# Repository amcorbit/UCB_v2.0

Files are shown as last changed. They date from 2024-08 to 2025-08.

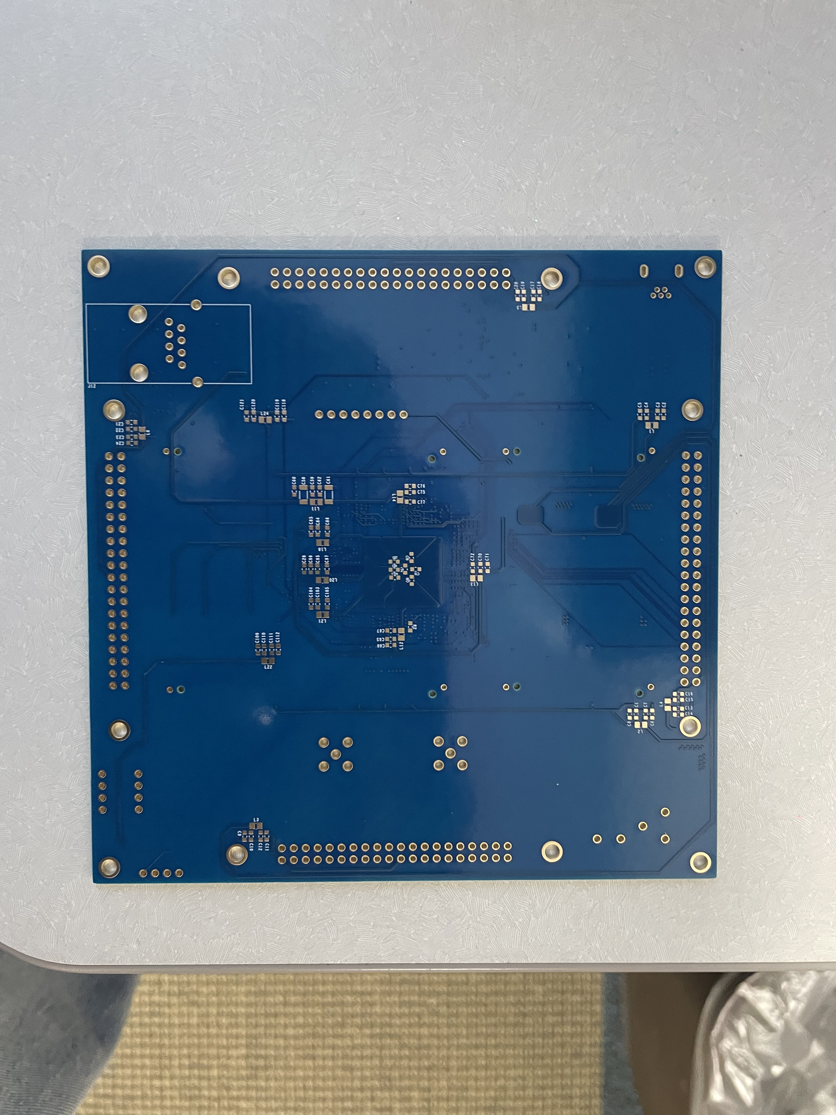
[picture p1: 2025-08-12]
Photos/IMG_9687 (1).jpeg

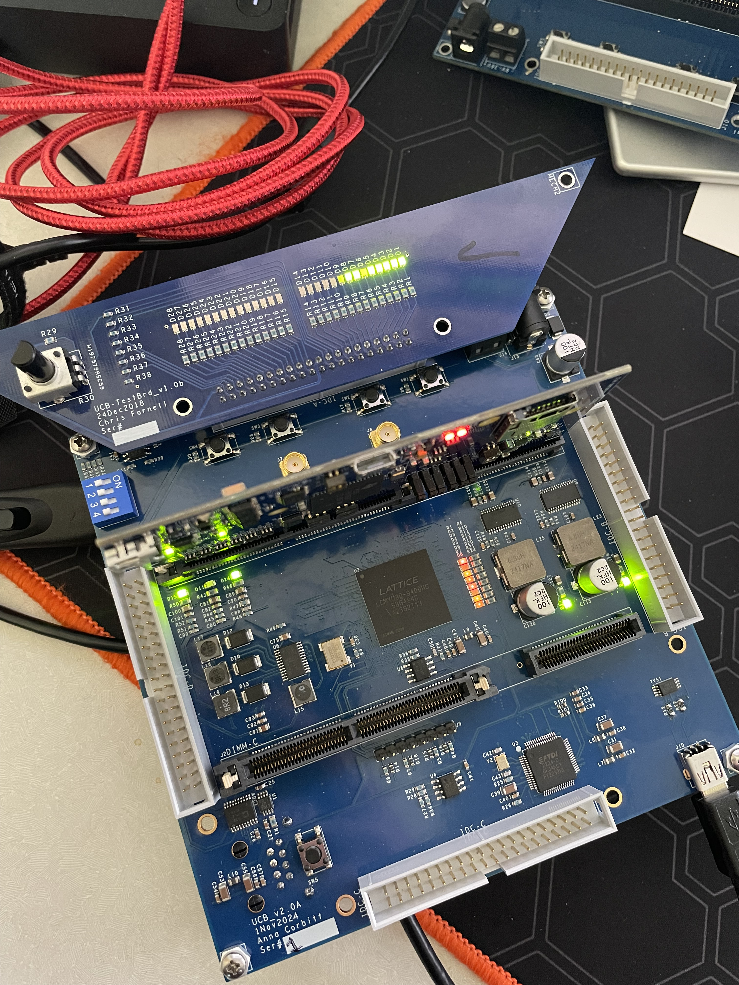
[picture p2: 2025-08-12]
Photos/IMG_9736 (1).jpeg

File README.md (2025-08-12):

This board was developed at the National Center for Reliable Electric Power Transmission (NCREPT) in collaboration with the University of Arkansas Power Group. It is an updated version of UCB v1.4a, which was developed by Dr. Chris Farnell. 

UCB v2.0 is an updated version of the existing UCB v1.4 architecture with additional features but a similar layout. 
The new version of the UCB includes an onboard SPI flash for storing and transferring information such as updated firmware. 
UCB v2.0 utilizes the Lattice MachXO3D FPGA instead of the MachXO2 for enhanced cybersecurity. 
The 100-Pin DIM slots on the original UCB v1.4 have been replaced with Texas Instruments’180-pin HSEC8 interface, allowing for the TMS320F28335 single core DSPs to be replaced with the TMS320F28379D dual core DSPs.
When compared to the F28335 DSP, the F28379D DSP has two 32-bit CPUs, a faster 200 MHz clock speed, additional programmable GPIO pins, an increased number of Pulse Width Modulator (PWM) channels, a larger flash, three SPI modules, and a 16-bit ADC.

Engineer: Anna Corbitt

Acknowledgments:

NCREPT Website: https://ncrept.uark.edu/

NCREPT Citation: A. Corbitt, W. G. Schwartz, C. Farnell, J. C. Balda and H. A. Mantooth, "The National Center for Reliable Electric Power Transmission Test Facility," in IEEE Open Journal of Power Electronics, vol. 5, pp. 754-764, 2024, doi: 10.1109/OJPEL.2024.3405311. 
Abstract: Globally, new technological solutions are being studied and developed by researchers in the field of power and energy systems. Before these solutions can be integrated into society as marketable products, thorough testing and validation of the design must be conducted. 
The National Center for Reliable Electric Power Transmission (NCREPT) is a unique high-power test facility located at the University of Arkansas, Fayetteville, AR, USA. NCREPT is a 12,000-square-foot laboratory space capable of testing power levels up to 6 MVA and offers testing at both the 480 V and 13.8 kV levels. 
NCREPT's capabilities expand outside of the scope of simply high-power testing. NCREPT has also supported experimental testing for transportation electrification, hardware-in-the-loop, and cybersecurity applications. 
NCREPT has personnel with experience testing new technologies and has demonstrated its innovative approaches by being a part of four R&D 100 award-winning projects. This paper gives an extensive overview of NCREPT, highlighting its significance as a state-of-the-art testing laboratory.

UA Power Group Website: https://uapower.group/

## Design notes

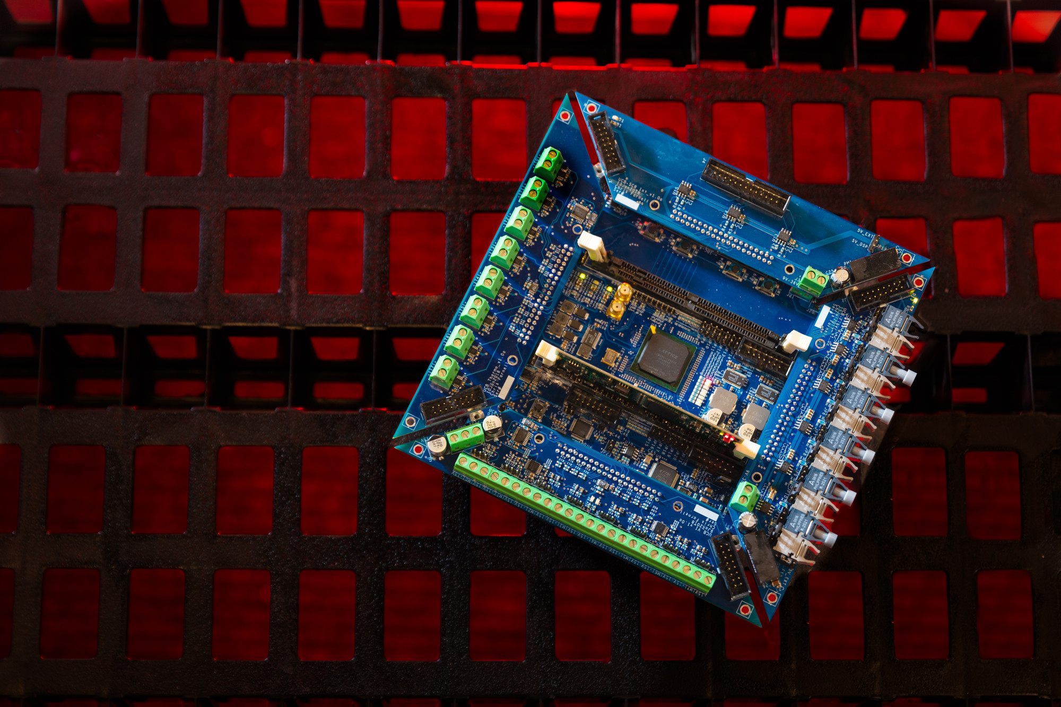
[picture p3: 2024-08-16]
Media/RS82903_9869_NCREPT_circuit_Board-engineering-2-lpr.jpg

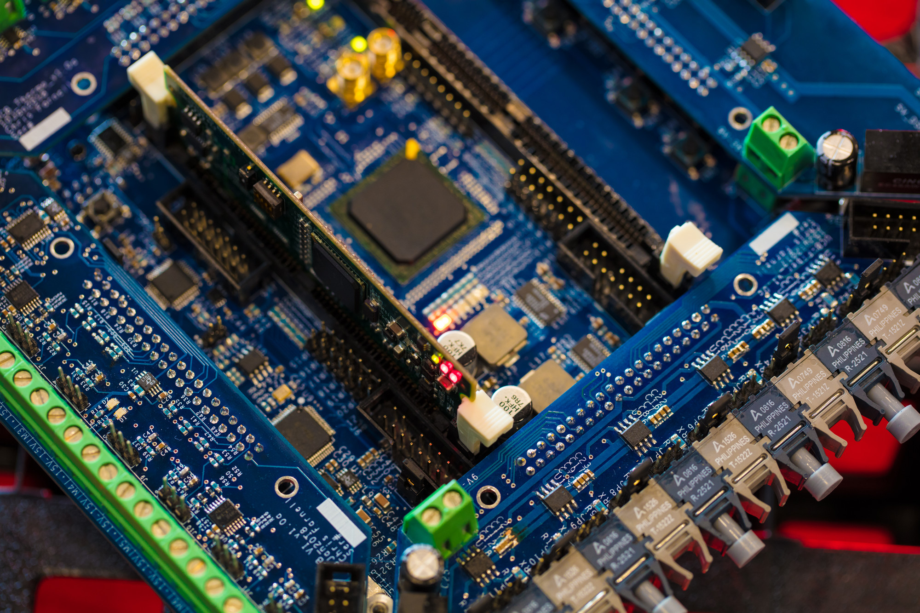
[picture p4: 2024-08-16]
Media/RS82902_9869_NCREPT_circuit_Board-engineering-1-lpr.jpg

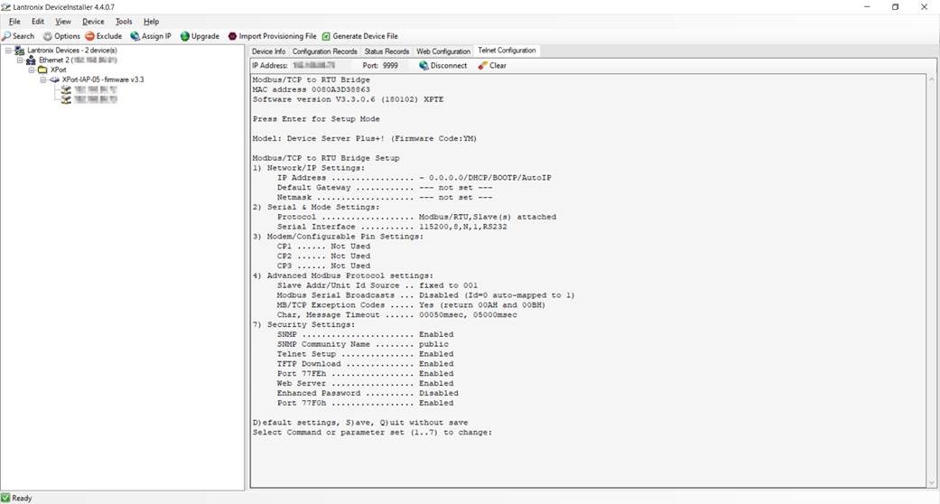
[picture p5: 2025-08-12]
Resources and Documentation/XPORT Configuration (1).jpg

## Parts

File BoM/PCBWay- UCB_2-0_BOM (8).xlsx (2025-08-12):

 |  |  | BOM
Item # | *Designator | *Qty | Manufacturer | *Mfg Part # | Description / Value | *Package/Footprint | Your Instructions / Notes
1 | ADC1 | 1 | Analog Devices Inc. | AD7928BRUZ | ADC 8-Ch, 12-Bit, 1MSPS | TSSOP-20 | SMD/SMT
2 | C1,C2,C4,C6,C9,C11,C13,C15,C17,C19,C21,C23,C25,C26,C27,C28,C33,C35,C48,C56,C59,C65,C67,C70,C72,C75,C77,C84,C86,C95,C97,C103,C105,C109,C111,C118,C120 | 37 | TDK | C1608X7R1V105K080AC | 1µF ±10% 35V X7R MLCC | C_0603 | SMD
3 | C3,C5,C7,C8,C10,C12,C14,C16,C18,C20,C22,C24,C29,C30,C32,C34,C36,C38,C40,C41,C46,C49,C51,C52,C54,C57,C60,C62,C66,C68,C71,C73,C76,C78,C82,C85,C87,C90,C92,C96,C98,C101,C104,C106,C107,C110,C112,C119,C121,C124 | 50 | TDK | C1608X7R1H104K080AA | 0.1µF ±10% 50V X7R MLCC | C_0603 | SMD
4 | C31,C37 | 2 | TDK | C3216X7R1H475K160AC | 4.7µF ±10% 50V X7R MLCC | C_1206 | SMD
5 | C39,C45,C47,C53,C55,C58,C61 | 7 | TDK | C3216X7R1V106M160AC | 10µF ±20% 35V X7R MLCC | C_1206 | SMD
6 | C42,C43 | 2 | TDK | C1608C0G1H180J080AA | 18pF ±5% 50V C0G MLCC | C_0603 | SMD
7 | C50,C80,C88,C99 | 4 | TDK | C1608C0G2A101K080AA | 100pF ±10% 100V C0G MLCC | C_0603 | SMD
8 | C63,C115,C128 | 3 | Panasonic | EEE-FK1H101P | 100uF ±20% 50V Electrolytic | EEE-FK-F | SMD
9 | C79,C91,C113,C114,C125,C126 | 6 | TDK | C2012X7R1H225M125AC | 2.2µF ±20% 50V X7R MLCC | C_0805 | SMD
10 | C81,C89,C100,C116,C127 | 5 | TDK | C2012X5R1E226M125AC | 22µF ±20% 25V X5R MLCC | C_0805 | SMD
11 | C93 | 1 | TDK | C1608X7R1H473K080AA | 0.047µF ±10% 50V X7R MLCC | C_0603 | SMD
12 | C122,C123,C129,C130 | 4 | TDK | C1608X7R2A103K080AA | 10nF ±10% 100V X7R MLCC | C_0604 | SMD
13 | D1,D5 | 2 | OSRAM | LH R974-LP-1 | LED, 0805, Red, VF= 1.8V | LED_0805-RED | 25mA
14 | D2,D6,D11,D14,D15,D16,D17 | 7 | OSRAM | LG R971-KN-1 | LED, 0805, Green, VF= 2.2V | LED_0805-GREEN | 25mA
15 | D3, D7 | 2 | OSRAM | LY R976-PS-36 | LED, 0805, Yellow, VF= 2.0V | LED_0805-YELLOW | 25mA
16 | D4, D8 | 2 | OSRAM | LO R976-PS-1 | LED, 0805, Orange, VF= 2.0V | LED_0805-ORANGE | 25mA
17 | D9,D10,D12,D13 | 4 | STMicroelectronics | STPS3150U | Schottky Diode 3A/150V | SMB (DO-214AA) | SMD
18 | J1A,J2A, J1B, J2B | 2 | Samtec Inc. | HSEC8-160-01-L-DV-A-BL and HSEC8-130-01-L-DV-A | 180 pin 120 HSEC8 socket, samtec and 180 pin 60 HSEC8 socket, samtec | HSEC180 | This is the HSEC 180 interface for texas instraments J1 and J2 each have two separate pieces (120 and 60)
19 | J3,J4,J5,J6 | 4 | Assmann | AWHW 40G-0202-T | 14-POS Header, Shrouded, 0.100", TH | 14-IDC-M | through hole
20 | J7,J8 | 2 | Samtec | SMA-J-P-H-ST-TH1 | SMA Jack, TH, 50 Ohms, 20 GHz, Threaded | SMA-J-P-H-ST-TH1
21 | J9 | 1 | Various | PRT-00116 | Male, TH, Straight, 8-Pos, 0.1" Pitch | H_1X8
22 | J10 | 1 | Molex | 54819-0519 | USB, Mini-B Receptacle Connector 5-POS, TH, Right Angle | USB_MINI-B_TH
23 | J11 | 1 | Various | PRT-00116 | Male, TH, Straight, 4-Pos, 0.1" Pitch | H_1x4
24 | J12 | 1 | Lantronix | XP1001000M-05R | XPort XE w/Modbus Ext Temp | XPORT
25 | J13 | 1 | CUI | PJ-102BH | DC Power Jack, 2.5mm Center Pin, TH | DC-PWR_JACK
26 | J14 | 1 | Phoenix Contact | 1985865 | PCB Terminal Block, 2-position, 90 degrees, 5.08mm, 10mm-Tall | 1985865 | 13.5A
27 | L1,L2,L3,L4,L5,L6,L7,L8,L9,L10,L11,L12,L13,L14,L18,L20,L21,L22,L24, | 19 | Murata | BLM21PG221SN1D | Ferrite Bead, 220 Ohm @ 100 MHz, 2A | L_0805 | 2A
28 | L15 | 1 | Wurth Electronics | 744042100 | 10uH, 1.3A, Fixed Inductor, ±30% | WE-TPC4828 | 1.3A
29 | L16 | 1 | Wurth Electronics | 744042003 | 3.3uH, 1.95A, Fixed Inductor, ±30% | WE-TPC4828 | 1.95A
30 | L17 | 1 | Wurth Electronics | 744042004 | 4.7uH, 1.72A, Fixed Inductor, ±30% | WE-TPC4828 | 1.72
31 | L19 | 1 | Wurth Electronics | 744042008 | 8.2uH, 1.4A, Fixed Inductor, ±30% | WE-TPC4828 | 1.4
32 | L23, L25 | 2 | Vishay | IHLP4040DZER6R8M11 | 6.8uH, 9.0A, Fixed Inductor, ±20% | L_4040 | 9.0A
33 | R6,R10,R11,R13,R19,R20,R21,R24,R43 | 9 | KOA Speer | RK73H2ATTD2200F | 220 Ohm, 1%, 0805 | R_0805 | 0.125W
34 | R1 | 1 | KOA Speer | RK73H2ATTD1001F | 1k Ohm, 1%, 0805 | R_0805 | 0.125W
35 | R2,R3,R9,R17,R23,R27,R28,R29,R30,R31,R32,R33,R35,R36,R37,R38,R56,R60 | 18 | KOA Speer | RK73H1JTTD1002F | 10k Ohm, 1%, 0603 | R_0603 | 0.1 W
36 | R4,R5,R7 | 3 | KOA Speer | RK73H1JTTD4701F | 4.7k Ohm, 1%, 0603 | R_0603 | 0.1 W
37 | R8,R26,R34 | 3 | KOA Speer | RK73H1JTTD2201F | 2.2k Ohm, 1%, 0603 | R_0603 | 0.1 W
38 | R12,R22 | 2 | KOA Speer | RK73Z2ATTD | 0 Ohm, 1%, 0805 | R_0805 | 0.125W
39 | R14,R15,R16,R18, R100, R101 | 6 | KOA Speer | RK73Z1JTTD | 0 Ohm Jumper, 0603 | R_0603 | 1A
40 | R25 | 1 | KOA Speer | RK73H1JTTD1202F | 12k Ohm, 1%, 0603 | R_0603 | 0.1W
41 | R39,R40,R41,R42 | 4 | KOA Speer | RK73H1JTTD56R0F | 56 Ohm, 1%, 0603 | R_0603 | 0.1W
42 | R44 | 1 | KOA Speer | RK73H1JTTD1272F | 12.7k Ohm, 1%, 0603 | R_0603 | 0.1W
43 | R45,R48,R52 | 3 | KOA Speer | RK73H1JTTD1022F | 10.2k Ohm, 1%, 0603 | R_0603 | 0.1W
44 | R46 | 1 | KOA Speer | RK73H2ATTD3300F | 330 Ohm, 1%, 0805 | R_0805 | 0.125W
45 | R47 | 1 | KOA Speer | RK73H1JTTD3162F | 31.6k Ohm, 1%, 0603 | R_0603 | 0.1W
46 | R49 | 1 | KOA Speer | RK73H1JTTD1822F | 18.2k Ohm, 1%, 0603 | R_0603 | 0.1W
47 | R50,R53,R57 | 3 | KOA Speer | RK73H2ATTD4700F | 470 Ohm, 1%, 0805 | R_0805 | 0.125W
48 | R51 | 1 | KOA Speer | RK73H1JTTD5362F | 53.6k Ohm, 1%, 0603 | R_0603 | 0.1W
49 | R54,R58 | 2 | KOA Speer | RK73H1JTTD1003F | 100k Ohm, 1%, 0603 | R_0603 | 0.1W
50 | R55,R59 | 2 | KOA Speer | RK73H1JTTDD2003F | 200k Ohm, 1%, 0603 | R_0603 | 0.1W
51 | SW1,SW2,SW3,SW4,SW5 | 5 | C&K Components | PTS645SL50SMTR92 LFS | Switch Tactile Momentary, N.O. | PTS645-SMD
52 | S1 | 1 | Jameco | DT-04-VP-R | Dip Switch, 4 Position, TH | SW-4_DIP
53 | TVS1 | 1 | TI | SN75240PWR | TVS Diode Arrays Dual USB Port | 8-TSSOP
54 | U1 | 1 | Linear Tech | LT1009CMS8#PBF | 2.5V Voltage Reference, ±0.2%, SMD | 8-MSOP
55 | U2 | 1 | Lattice | LCMXO3D-9400HC-5BG484C | FPGA - Field Programmable Gate Array Lattice MachXO3D; 9400LUTs 2.5V/3.3V | 484-ball caBGA (19 mm x 19 mm)
56 | U3 | 1 | FTDI | FT2232HL | USB Interface IC USB to Dual UART/ FIFO/SPI/JTAG/I2C (Lattice) | LQFP-64
57 | U4 | 1 | Microchip | 93LC56C-I/SN | EEPROM, 128x16 or 256x8, 2kb, Serial, 3-Wire, Microwire | 8-SOIC
58 | U6 | 1 | Macronix | MX25V1635FM1I | IC FLASH 16MBIT SPI/QUAD 8SOP | 8-SOIC
59 | U7 | 1 | Silicon Labs | Si8621BC-B-IS | Digital Isolator, 3.75kV, 1TX/1RX, 150Mbps | Si861x-2x
60 | U8 | 1 | Linear Tech | LT3514EFE#PBF-ND | Buck Ctrl, 3-Ch Vin(3.2V-36V), [2A, 1A, 1A] | 24-TSSOP_EP
61 | U9,U10 | 2 | Linear Tech | LTC3649EFE#PBF | Buck Ctrl, Synchronous, 1-Ch Vin(3.1V-60V), [4A] | 28-TSSOP_EP
62 | Y1 | 1 | CTS | CB3LV-3C-50M0000 | Crystals, 50.000MHz 50ppm 50pF, 3.3V | CTS-CB3
63 | Y2 | 1 | TXC Corp | 7M-12.000MAAJ-T | Crystals, 12.000MHz 30ppm -20 +70C 18pF | TXC-7M
Need a quick and accurante quote? Need an efficient production? Please read SMT Ordering Necessary Files & Info in 1 minute. Thank you very much! (https://www.pcbway.com/smt_ordering_guide.html)
Click for Instructions on How to Create a BOM (https://www.pcbway.com/blog/PCB_Assembly/How_to_Build_a_BOM__Bill_Of_Materials_.html)

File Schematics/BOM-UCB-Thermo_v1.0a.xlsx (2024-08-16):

Item Number | Quantity | Value | Description | Part Reference | Manufacturer | Manufacturer_Part_Number | Distributor | Distributor_Part_Number | Price | Ext_Price
1 | 1 | AD7928BRUZ | ADC 8-Ch, 12-Bit, 1MSPS | ADC1 | Analog Devices | AD7928BRUZ | Mouser | 584-AD7928BRUZ | $11.07 | $11.07
2 | 25 | 1uF | 1µF ±10% 35V X7R MLCC | C25,C27,C28,C30,C31,C35,C38,C39,C40,C60,C61,C65,C66,C70,C71,C75,C76,C80,C81,C85,C86,C90,C91,C95,C96 | TDK | C1608X7R1V105K080AC | Digi-Key | 445-7414-1-ND | $0.10 | $2.50
3 | 20 | 0.1uF | 0.1µF ±10% 50V X7R MLCC | C26,C29,C32,C34,C62,C63,C67,C68,C72,C73,C77,C78,C82,C83,C87,C88,C92,C93,C97,C98 | TDK | C1608X7R1H104K080AA | Digi-Key | 445-1314-1-ND | $0.02 | $0.40
4 | 1 | 10nF | 10nF ±10% 100V X7R MLCC | C33 | TDK | C1608X7R2A103K080AA | Mouser | 810-C1608X7R2A103K | $0.02 | $0.02
5 | 8 | 10uF | 10µF ±20% 35V X7R MLCC | C59,C64,C69,C74,C79,C84,C89,C94 | TDK | C3216X7R1V106M160AC | Digi-Key | 445-8034-1-ND | $0.36 | $2.88
6 | 1 | SFH11-PBPC-D20-ST-BK | 40-POS Header, Shrouded, 0.100", TH, Female w/ Mounting | J3 | Sullins | SFH11-PBPC-D20-ST-BK | Digi-Key | S9200-ND | $2.31 | $2.31
7 | 1 | AWHW 16G-0202-T | 16-POS Header, Shrouded, 0.100", TH | J4 | Assmann | AWHW 16G-0202-T | Digi-Key | AWHW 16G-0202-T-ND
8 | 8 | 1715721 | PCB Terminal Block, 2-position, 90 degrees, 5.08mm | J5,J6,J7,J8,J9,J10,J11,J12 | Phoenix Contact | 1715721 | Mouser | 651-1715721 | $1.17 | $9.36
9 | 1 | 220 | Ferrite Bead, 220 Ohm @ 100 MHz, 2A | L1 | Murata | BLM21PG221SN1D | Digi-Key | 490-1054-1-ND | $0.09 | $0.09
10 | 2 | Mech_Hole | Mounting Hole for 4-40 Screw, 0.125" | MECH1,MECH2
11 | 2 | 1k | 1k Ohm, 1%, 0805 | R3,R8 | KOA Speer | RK73H2ATTD1001F | Mouser | 660-RK73H2ATTD1001F | $0.01 | $0.03
12 | 24 | 10k | 10k Ohm, 1%, 0603 | R15,R17,R23,R29,R35,R41,R47,R53,R59,R60,R63,R64,R66,R67,R69,R70,R72,R73,R75,R76,R78,R79,R81,R82 | KOA Speer | RK73H1JTTD1002F | Mouser | 660-RK73H1JTTD1002F | $0.01 | $0.31
13 | 8 | 15k | 15k Ohm, 1%, 0603 | R16,R18,R24,R30,R36,R42,R48,R54 | KOA Speer | RK73H1JTTD1502F | Mouser | 660-RK73H1JTTD1502F | $0.01 | $0.10
14 | 8 | 1Meg | 1M Ohm, 1%, 0603 | R61,R62,R65,R68,R71,R74,R77,R80 | KOA Speer | RK73H1JTTD1004F | Mouser | 660-RK73H1JTTD1004F | $0.01 | $0.10
15 | 2 | LT1009CZ | 2.5V Voltage Reference, ±0.2%, SMD | U1,U4 | Linear Tech | LT1009CMS8#PBF | Digi-Key | LT1009CMS8#PBF-ND | $3.77 | $7.54
16 | 1 | TPS79533 | LDO Voltage Reg, 3.3V, 500mA, 2% | U2 | TI | TPS79533DCQR | Mouser | 595-TPS79533DCQR | $2.92 | $2.92
17 | 8 | AD8495ARMZ | K-Type Thermocouple Amplifier w/ Cold Jct Comp | U7,U8,U9,U10,U11,U12,U13,U14 | Analog Devices | AD8495ARMZ-ND | Mouser | 584-AD8495ARMZ | $5.81 | $46.48
 |  |  |  |  |  |  |  |  |  | $86.12

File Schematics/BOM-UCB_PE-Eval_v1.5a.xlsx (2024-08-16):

Item Number | Quantity | Value | Description | Part Reference | Manufacturer | Manufacturer_Part_Number | Distributor | Distributor_Part_Number | Price
1 | 1 | AD7928BRUZ | ADC 8-Ch, 12-Bit, 1MSPS | ADC1 | Analog Devices | AD7928BRUZ | Mouser | 584-AD7928BRUZ | 11.07
2 | 3 | 10uF | Film Capacitor, 10uF, 250Vdc | C1,C2,C3 | Panasonic | ECQ-E2106KFB | Mouser | 667-ECQ-E2106KFB | 3.58
3 | 4 | 100uF | Electrolytic Capacitor (50V/100uF) | C4,C5,C34,C35 | Nichicon | UVZ1H101MPD | Mouser | 647-UVZ1H101MPD | 0.23
4 | 12 | 10uF | 10µF ±20% 35V X7R MLCC | C16,C21,C22,C23,C24,C25,C26,C27,C28,C29,C54,C55 | TDK | C3216X7R1V106M160AC | Digi-Key | 445-8034-1-ND | 0.36
5 | 12 | 1uF | 1µF ±10% 35V X7R MLCC | C17,C30,C31,C32,C33,C56,C57,C96,C97,C98,C99,C102 | TDK | C1608X7R1V105K080AC | Digi-Key | 445-7414-1-ND | 0.1
6 | 9 | 4.7uF | 4.7µF ±10% 50V X7R MLCC | C18,C36,C37,C38,C39,C40,C41,C42,C43 | TDK | C3216X7R1H475K160AC | Digi-Key | 445-8032-1-ND | 0.8
7 | 1 | 2.2nF | 2.2nF ±10% 100V X7R MLCC | C19 | TDK | C1608X7R2A222K080AA | Digi-Key | 445-1300-1-ND | 0.02
8 | 1 | 4.7nF | 4.7nF ±10% 100V X7R MLCC | C20 | TDK | C1608X7R2A472K080AA | Digi-Key | 445-1302-1-ND | 0.03
9 | 23 | 0.1uF | 0.1µF ±10% 50V X7R MLCC | C44,C45,C46,C52,C53,C59,C60,C64,C65,C69,C70,C74,C75,C79,C80,C84,C85,C95,C100,C103,C106,C107,C109 | TDK | C1608X7R1H104K080AA | Digi-Key | 445-1314-1-ND | 0.02
10 | 9 | 1nF | 1nF ±10% 100V X7R MLCC | C47,C48,C49,C50,C51,C94,C104,C105,C108 | TDK | C1608X7R2A102K080AA | Digi-Key | 445-1298-1-ND | 0.02
11 | 18 | 100pF | 100pF ±10% 100V C0G MLCC | C58,C61,C62,C63,C66,C67,C68,C71,C72,C73,C76,C77,C78,C81,C82,C83,C86,C87 | TDK | C1608C0G2A101K080AA | Digi-Key | 445-14003-1-ND | 0.02
12 | 2 | 220pF | 0.22nF ±5% 100V C0G MLCC | C88,C89 | TDK | C1608C0G2A221J080AA | Digi-Key | 445-2308-1-ND | 0.03
13 | 1 | STPS3150U | Schottky Diode 3A/150V | D1 | ST | STPS3150U | Digi-Key | 497-6583-1-ND | 0.54
14 | 7 | DFLS260-7 | Schottky Diode 2A/60V | D5,D6,D7,D8,D9,D15,D16 | Diodes Incorporated | DFLS260-7 | Mouser | 621-DFLS260-7 | 0.397
15 | 5 | DFLZ18-7 | Zener Diode 18V 1W | D10,D11,D12,D13,D14 | Diodes Incorporated | DFLZ18-7 | Digi-Key | DFLZ18DICT-ND | 0.387
16 | 3 | LED-R | LED, 0805, Red, VF= 1.8V | D17,D22,D26 | OSRAM | LH R974-LP-1 | Mouser | 720-LHR974-LP-1 | 0.171
17 | 3 | LED-G | LED, 0805, Green, VF= 2.2V | D18,D19,D23 | OSRAM | LG R971-KN-1 | Mouser | 720-LGR971-KN-1 | 0.171
18 | 2 | LED-Y | LED, 0805, Yellow, VF= 2.0V | D20,D24 | OSRAM | LY R976-PS-36 | Mouser | 720-LYR976-PS-36 | 0.18
19 | 2 | LED-O | LED, 0805, Orange, VF= 2.0V | D21,D25 | OSRAM | LO R976-PS-1 | Mouser | 720-LOR976-PS-1 | 0.18
20 | 1 | 65600001009 | Fuse Holder, 5x20mm, TH | F1 | Littelfuse | 65600001009 | Mouser | 576-65600001009 | 0.68
21 | 1 | AWHW 40G-0202-T | 40-POS Header, Shrouded, 0.100", TH | J1 | Assmann | AWHW 40G-0202-T | Digi-Key | AWHW 40G-0202-T-ND | 0.95
22 | 4 | 1715721 | PCB Terminal Block, 2-position, 90 degrees, 5.08mm | J2,J4,J5,J8 | Phoenix Contact | 1715721 | Mouser | 651-1715721 | 1.17
23 | 1 | 1715734 | PCB Terminal Block, 3-position, 90 degrees, 5.08mm | J3 | Phoenix Contact | 1715734 | Mouser | 651-1715734 | 1.72
24 | 1 | PJ-102BH | DC Power Jack, 2.5mm Center Pin, TH | J6 | CUI | PJ-102BH | Mouser | 490-PJ-102BH | 1.18
25 | 1 | AWHW 10G-0202-T | 10-POS Header, Shrouded, 0.100", TH | J7 | Assmann | AWHW 10G-0202-T | Digi-Key | AE11232-ND | 0.63
26 | 2 |  | Male, TH, Straight, 2-Pos, 0.1" Pitch | JP1,JP2 | Various | PRT-00116 | Sparkfun | PRT-00116 | 0.15
27 | 2 |  | Male, TH, Straight, 3-Pos, 0.1" Pitch | JP3,JP4 | Various | PRT-00116 | Sparkfun | PRT-00116 | 0.15
28 | 3 | 180uH | 180uH, 4.0A, PCV-2 | L1,L2,L3 | CoilCraft | PCV-2-184-05L | CoilCraft | PCV-2-184-05L | 3.44
29 | 2 | 560uH | 560uH, 2.6A, PCV-2 | L4,L5 | CoilCraft | PCV-2-564-02L | CoilCraft | PCV-2-564-02L | 3.78
30 | 4 | Mech_Hole | Mounting Hole for 4-40 Screw, 0.125" | MECH1,MECH2,MECH3,MECH4
31 | 1 | EC4SAW-24S33N | Isolated DC/DC Converters 5 Watt, 9-36 Vin, 3.3 Vout | PM1 | Cincon | EC4SAW-24S33N | Mouser | 418-EC4SAW-24S33N | 11.36
32 | 2 | EC4SAW-24S05N | Isolated DC/DC Converters 6 Watt, 9-36 Vin, 5 Vout | PM2,PM3 | Cincon | EC4SAW-24S05N | Mouser | 418-EC4SAW-24S05N | 11.36
33 | 8 | STGP15H60DF | IGBT Trench gate 600V 15A | Q1,Q2,Q3,Q4,Q5,Q6,Q7,Q8 | STMicroelectrionics | STGP15H60DF | Mouser | 511-STGP15H60DF | 2.13
34 | 1 | Si7898DP | Si N-Chan MOSFET 150V/3A | Q9 | Vishay | SI7898DP-T1-E3 | Digi-Key | SI7898DP-T1-E3CT-ND | 1.67
35 | 1 | 825k | 825k Ohm, 1%, 0603 | R8 | KOA Speer | RK73H1JTTD8253F | Mouser | 660-RK73H1JTTD8253F | 0.013
36 | 1 | 215k | 215k Ohm, 1%, 0603 | R9 | KOA Speer | RK73H1JTTD2153F | Mouser | 660-RK73H1JTTD2153F | 0.013
37 | 1 | 133k | 133k Ohm, 1%, 0603 | R10 | KOA Speer | RK73H1JTTD1333F | Mouser | 660-RK73H1JTTD1333F | 0.013
38 | 29 | 10k | 10k Ohm, 1%, 0603 | R11,R35,R36,R37,R38,R41,R42,R43,R44,R47,R48,R49,R50,R53,R54,R55,R56,R59,R60,R61,R62,R65,R66,R67,R68,R70,R72,R78,R79 | KOA Speer | RK73H1JTTD1002F | Mouser | 660-RK73H1JTTD1002F | 0.013
39 | 1 | 71.5k | 71.5k Ohm, 1%, 0603 | R12 | KOA Speer | RK73H1JTTD7152F | Mouser | 660-RK73H1JTTD7152F | 0.013
40 | 1 | 6.04k | 6.04k Ohm, 1%, 0603 | R13 | KOA Speer | RK73H1JTTD6041F | Mouser | 660-RK73H1JTTD6041F | 0.013
41 | 1 | 0.01 | 10m Ohm, 1%, 1206, Current Sense Res | R14 | KOA Speer | UR73VD2BTTD10L0F | Mouser | 660-UR73VD2BTTD10L0F | 0.88
42 | 2 | 2.49k | 2.49k Ohm, 1%, 2512 | R15,R16 | KOA Speer | RK73H3ATTE2491F | Mouser | 660-RK73H3ATTE2491F | 0.214
43 | 8 | 120 | 120 Ohm, 1%, 1206 | R17,R19,R21,R23,R25,R27,R29,R31 | KOA Speer | RK73H2BTTD1200F | Mouser | 660-RK73H2BTTD1200F | 0.022
44 | 8 | 10 | 10 Ohm, 1%, 1206 | R18,R20,R22,R24,R26,R28,R30,R32 | KOA Speer | RK73H2BTTD10R0F | Mouser | 660-RK73H2BTTD10R0F | 0.022
45 | 7 | 1Meg | 1M Ohm, 1%,1206 | R33,R40,R46,R52,R58,R64,R88 | KOA Speer | RK73H2BTTD1004F | Mouser | 660-RK73H2BTTD1004F | 0.022
46 | 6 | 31.6k | 31.6k Ohm, 1%, 0603 | R39,R45,R51,R57,R63,R69 | KOA Speer | RK73H1JTTD3162F | Mouser | 660-RK73H1JTTD3162F | 0.013
47 | 2 | 15k | 15k Ohm, 1%, 0603 | R71,R73 | KOA Speer | RK73H1JTTD1502F | Mouser | 660-RK73H1JTTD1502F | 0.013
48 | 1 | PTV09A-4020F-B103 | Potentiometer 10k Linear, 6mm Shaft,TH | R74 | Bourns | PTV09A-4020F-B103 | Mouser | 652-PTV09A-4020FB103 | 0.74
49 | 1 | 1k | 1k Ohm, 1%, 0805 | R75 | KOA Speer | RK73H2ATTD1001F | Mouser | 660-RK73H2ATTD1001F | 0.014
50 | 2 | 330 | 330 Ohm, 1%, 0805 | R76,R77 | KOA Speer | RK73H2ATTD3300F | Mouser | 660-RK73H2ATTD3300F | 0.014
51 | 8 | 220 | 220 Ohm, 1%, 0805 | R80,R81,R82,R83,R84,R85,R86,R87 | KOA Speer | RK73H2ATTD2200F | Mouser | 660-RK73H2ATTD2200F | 0.014
52 | 1 | G13JPCF | Switch Toggle, SPDT, R/G LED (TH Pads) | SW8 | NKK Switches | G13JPCF | Digi-Key | 360-1698-ND | 7.16
53 | 9 | TP-Y | PCB Test Point TH Yellow | TP1,TP2,TP3,TP4,TP5,TP6,TP7,TP8,TP9 | Keystone Electronics | 5004 | Mouser | 534-5004 | 0.32
54 | 1 | VP1-0102-R | 6.5µH, 0.8A, 6-Winding XFMR, VTP1, 20% | TX1 | Eaton | VP1-0102-R | Digi-Key | 283-3659-1-ND | 7.5
55 | 9 | ACS714LLCTR-05B-T | Hall Effect Sensor, 5A AC/DC,185mV/A | U1,U4,U5,U6,U7,U26,U29,U30,U31 | Allegro | ACS714LLCTR-05B-T | Digi-Key | 620-1225-1-ND | 5.05
56 | 1 | LT3748EMS#PBF-ND | Flyback Controller (Used with VP1 Arrays) | U3 | Linear Tech | LT3748EMS#PBF-ND | Digi-Key | LT3748EMS#PBF-ND | 6.66
57 | 8 | HCPL-3120-300E | 2.5 Amp IGBT Gate Drive, Optocoupler, Gullwing | U8,U9,U10,U11,U12,U13,U14,U15 | Avago | HCPL-3120-300E | Mouser | 630-HCPL-3120-300E | 2.99
58 | 2 | OPA4322AIPWR | Quad OpAmp, 20 MHz | U16,U17 | TI | OPA4322AIPWR | Digi-Key | 296-36702-1-ND | 3.07
59 | 6 | ACPL-C87B | Isolation OpAmp, 100 kHz | U20,U21,U22,U23,U24,U25 | Avago | ACPL-C87B-000E | Digi-Key | 516-2579-5-ND | 7.64
60 | 1 | LT1009CZ | 2.5V Voltage Reference, ±0.2%, SMD | U27 | Linear Tech | LT1009CMS8#PBF | Digi-Key | LT1009CMS8#PBF-ND | 3.77
61 | 1 | SN74LVC2G07DBVR | Dual Open-Drain Buffer | U28 | TI | SN74LVC2G07DBVR | Digi-Key | 296-13494-1-ND | 0.54

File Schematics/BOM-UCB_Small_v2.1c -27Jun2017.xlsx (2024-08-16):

Item Number | Quantity | Order | Value | Description | Part Reference | Manufacturer | Manufacturer_Part_Number | Distributor | Distributor_Part_Number | Price | ExtPrice | Notes | Actually Ordered
1 | 1 | 5 | 100uF | Electrolytic Capacitor (50V/100uF) | C1 | Nichicon | UVZ1H101MPD (http://www.mouser.com/ProductDetail/Nichicon/UVZ1H101MPD/) | Mouser | 647-UVZ1H101MPD | $0.23 | $1.15
2 | 3 | 10 | 10uF | 10µF ±20% 35V X7R MLCC | C2,C4,C6 | TDK | C3216X7R1V106M160AC (http://www.digikey.com/product-detail/en/tdk-corporation/C3216X7R1V106M160AC/445-8034-1-ND/2792174) | Digi-Key | 445-8034-1-ND | $0.36 | $3.60 | DigiKey | C3216X7R1V106M160AE
3 | 11 | 100 | 0.1uF | 0.1µF ±10% 50V X7R MLCC | C3,C5,C7,C8,C9,C10,C13,C14,C15,C16,C17 | TDK | C1608X7R1H104K080AA (http://www.digikey.com/product-detail/en/tdk-corporation/C1608X7R1H104K080AA/445-1314-1-ND/567687) | Digi-Key | 445-1314-1-ND | $0.02 | $2.00 |  | C1608X7R1H104M080AA
4 | 2 | 10 | 1uF | 1µF ±10% 35V X7R MLCC | C11,C12 | TDK | C1608X7R1V105K080AC (http://www.mouser.com/ProductDetail/TDK/C1608X7R1V105K080AC/) | Mouser | 810-C1608X7R1V105KAC | $0.20 | $2.00
5 | 1 | 10 | LED-G | LED, 0805, Green, VF= 2.2V | D1 | OSRAM | LG R971-KN-1 (http://www.mouser.com/ProductDetail/Osram-Opto-Semiconductor/LG-R971-KN-1/) | Mouser | 720-LGR971-KN-1 | $0.17 | $1.71
6 | 1 | 1 | F28335_DIMM | DIMM 100 connector for TI F28335 DSP | J1 | AMP | 5390213-1 (http://www.mouser.com/ProductDetail/TE-Connectivity/5390213-1/) | Mouser | 571-5390213-1 | $3.69 | $3.69
7 | 1 | 1 | AWHW 14G-0202-T | 14-POS Header, Shrouded, 0.100", TH | J2 | Assmann | AWHW 14G-0202-T (http://www.digikey.com/product-detail/en/assmann-wsw-components/AWHW-14G-0202-T/AWHW-14G-0202-T-ND/5224931) | Digi-Key | AWHW 14G-0202-T-ND | $0.63 | $0.63 | DigiKey
8 | 4 | 4 | Header-4 | Male, TH, Straight, 4-Pos, 0.1" Pitch | J3,J11,J12,J13 | Various | PRT-00116 (https://www.sparkfun.com/products/116) | Sparkfun | PRT-00116 | $0.15 | $0.60
9 | 1 | 1 | Header_1x22 | Male, TH, Straight, 22-Pos, 0.1" Pitch | J4 | Various | PRT-00116 (https://www.sparkfun.com/products/116) | Sparkfun | PRT-00116 | $0.15 | $0.15
10 | 1 | 1 | Header_1x25 | Male, TH, Straight, 25-Pos, 0.1" Pitch | J5 | Various | PRT-00116 | Sparkfun | PRT-00116 | $0.15 | $0.15
11 | 2 | 2 | Header_1x8 | Male, TH, Straight, 8-Pos, 0.1" Pitch | J6,J7 | Various | PRT-00116 | Sparkfun | PRT-00116 | $0.15 | $0.30
12 | 1 | 1 | PJ-102BH | DC Power Jack, 2.5mm Center Pin, TH | J8 | CUI | PJ-102BH (http://www.mouser.com/ProductDetail/CUI-Inc/PJ-102BH/) | Mouser | 490-PJ-102BH | $1.18 | $1.18
13 | 1 | 1 | 1715721 | PCB Terminal Block, 2-position, 90 degrees, 5.08mm | J9 | Phoenix Contact | 1715721 (http://www.mouser.com/ProductDetail/Phoenix-Contact/1715721/?qs=sGAEpiMZZMuVJC7Vq%252bMl51nuzzLebwED) | Mouser | 651-1715721 | $1.17 | $1.17
14 | 1 | 5 | 670687041 | USB - B Receptacle Connector 4-POS, TH, Right Angle | J10 | Molex | 670687041 (http://www.digikey.com/product-search/en?keywords=670687041) | Digi-Key | WM3463-ND | $1.59 | $7.95
15 | 2 | 10 | AWHW 40G-0202-T | 40-POS Header, Shrouded, 0.100", TH, Male w/ Mounting | J14,J15 | Assmann | AWHW 40G-0202-T (http://www.digikey.com/product-detail/en/assmann-wsw-components/AWHW-40G-0202-T/AWHW-40G-0202-T-ND/5224935) | Digi-Key | AWHW 40G-0202-T-ND | $0.95 | $9.50 | DigiKey
16 | 3 | 3 | Header-2 | Male, TH, Straight, 2-Pos, 0.1" Pitch | J16,J17,J18 | Various | PRT-00116 (https://www.sparkfun.com/products/116) | Sparkfun | PRT-00116 | $0.15 | $0.45
17 | 1 | 1 |  | Male, TH, Straight, 3-Pos, 0.1" Pitch | JP1 | Various | PRT-00116 (https://www.sparkfun.com/products/116) | Sparkfun | PRT-00116 | $0.15 | $0.15
18 | 11 | 11 |  | Male, TH, Straight, 2-Pos, 0.1" Pitch | JP2,JP3,JP4,JP5,JP6,JP7,JP8,JP9,JP10,JP11,JP12 | Various | PRT-00116 | Sparkfun | PRT-00116 | $0.15 | $1.65
19 | 1 | 1 | 22uH | 22uH,13mA, Fixed Inductor, ±30% | L1 | Murata | LQM21FN220N00L (http://www.mouser.com/ProductDetail/Murata/LQM21FN220N00L/) | Mouser | 81-LQM21FN220N00L | $0.14 | $0.14
20 | 4 | 4 | Mech_Hole | Mounting Hole for 4-40 Screw, 0.125" | MECH1,MECH2,MECH3,MECH4
21 | 1 | 2 | EC4SAW-24S05N | Isolated DC/DC Converters 6 Watt, 9-36 Vin, 5 Vout | PM1 | Cincon | EC4SAW-24S05N (http://www.mouser.com/ProductDetail/Cincon/EC4SAW-24S05N/) | Mouser | 418-EC4SAW-24S05N | $11.36 | $22.72 | Out of Stock
 | 1 |  | EC3SAW-24S05P | Isolated DC/DC Converters 3 Watt, 9-36 Vin, 5 Vout | PM1 | Cincon | EC3SAW-24S05P | Mouser | 418-EC3SAW-24S05P | $11.74 | $11.74 | Replacement for above
22 | 2 | 100 | 470 | 470 Ohm, 1%, 0805 | R1,R6 | KOA Speer | RK73H2ATTD4700F (http://www.mouser.com/ProductDetail/KOA-Speer/RK73H2ATTD4700F/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) | Mouser | 660-RK73H2ATTD4700F | $0.01 | $1.40
23 | 2 | 100 | 27 | 27 Ohm, 1%, 0805 | R2,R3 | KOA Speer | RK73H2ATTD27R0F (http://www.mouser.com/ProductDetail/KOA-Speer/RK73H2ATTD27R0F/) | Mouser | 660-RK73H2ATTD27R0F | $0.01 | $1.40
24 | 2 | 100 | 2.2k | 2.2k Ohm, 1%, 0805 | R4,R7 | KOA Speer | RK73H2ATTD2201F (http://www.mouser.com/ProductDetail/KOA-Speer/RK73H2ATTD2201F/) | Mouser | 660-RK73H2ATTD2201F | $0.01 | $1.40
25 | 1 | 100 | 1Meg | 1Meg Ohm, 1%, 0805 | R5 | KOA Speer | RK73H2ATTD1004F (http://www.mouser.com/ProductDetail/KOA-Speer/RK73H2ATTD1004F/) | Mouser | 660-RK73H2ATTD1004F | $0.01 | $1.40
26 | 1 | 100 | 10k | 10k Ohm, 1%, 0805 | R8 | KOA Speer | RK73H2ATTD1002F (http://www.mouser.com/ProductDetail/KOA-Speer/RK73H2ATTD1002F/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) | Mouser | 660-RK73H2ATTD1002F | $0.01 | $1.40 | Out of Stock
27 | 2 | 100 | 1k | 1k Ohm, 1%, 0805 | R9,R11 | KOA Speer | RK73H2ATTD1001F (http://www.mouser.com/ProductDetail/KOA-Speer/RK73H2ATTD1001F/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) | Mouser | 660-RK73H2ATTD1001F | $0.01 | $1.40 | Out of Stock
28 | 1 | 100 | 47k | 47k Ohm, 1%, 0805 | R10 | KOA Speer | RK73H2ATTD4702F (http://www.mouser.com/ProductDetail/KOA-Speer/RK73H2ATTD4702F/) | Mouser | 660-RK73H2ATTD4702F | $0.01 | $1.40 | Out of Stock
29 | 7 | 100 | 2.7k | 2.7k Ohm, 1%, 0805 | R12,R13,R14,R15,R16,R17,R18 | KOA Speer | RK73H2ATTD2701F (http://www.mouser.com/ProductDetail/KOA-Speer/RK73H2ATTD2701F/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) | Mouser | 660-RK73H2ATTD2701F | $0.01 | $1.40
30 | 1 | 2 | SN75240PWR | TVS Diode Arrays Dual USB Port | TVS1 | TI | SN75240PWR (http://www.mouser.com/ProductDetail/Texas-Instruments/SN75240PWR/?qs=sGAEpiMZZMtYFXwiBRPs0wJvaaFd6rFX) | Mouser | 595-SN75240PWR | $1.22 | $2.44
31 | 1 | 2 | FT2232D | USB Interface IC USB to Dual UART/ FIFO/SPI/JTAG/I2C (TI) | U1 | FTDI | FT2232D-REEL (http://www.mouser.com/ProductDetail/FTDI/FT2232D-REEL/) | Mouser | 895-FT2232D | $6.99 | $13.98
32 | 1 | 2 | TPS79533 | LDO Voltage Reg, 3.3V, 500mA, 2% | U2 | TI | TPS79533DCQR (http://www.mouser.com/ProductDetail/Texas-Instruments/TPS79533DCQR/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) | Mouser | 595-TPS79533DCQR | $2.92 | $5.84
33 | 1 | 2 | SN74LVC2G74 | Flip Flops Single Pos Edge Trig | U4 | TI | SN74LVC2G74 (http://www.mouser.com/ProductDetail/Texas-Instruments/SN74LVC2G74MDCUTEP/) | Mouser | 595-SN74LVC2G74DCTR | $0.60 | $1.20
34 | 1 | 2 | 6 MHz | 6MHz Ceramic Resonator Built in Capacitor 15pF ±0.2% | U5 | Murata | CSTCR6M00G53Z-R0 (http://www.mouser.com/ProductDetail/Murata/CSTCR6M00G53Z-R0/) | Mouser | 81-CSTCR6M00G53Z-R0 | $0.44 | $0.88
35 | 1 | 2 | 93LC46BT-I/OT | EEPROM 64x16, 1kb, Serial, 3-Wire, Microwire | U6 | Microchip | 93LC46BT-I/OT (http://www.mouser.com/ProductDetail/Microchip/93LC46BT-I-OT/) | Mouser | 579-93LC46BT-I/OT | $0.24 | $0.48
 |  |  | Total
 |  |  | $108.65
 |  |  |  | 14-Pin IDC Cable (12in)
 |  |  |  | 40-Pin IDC Cable (6in)
 |  |  |  | TMDSCNCD28335

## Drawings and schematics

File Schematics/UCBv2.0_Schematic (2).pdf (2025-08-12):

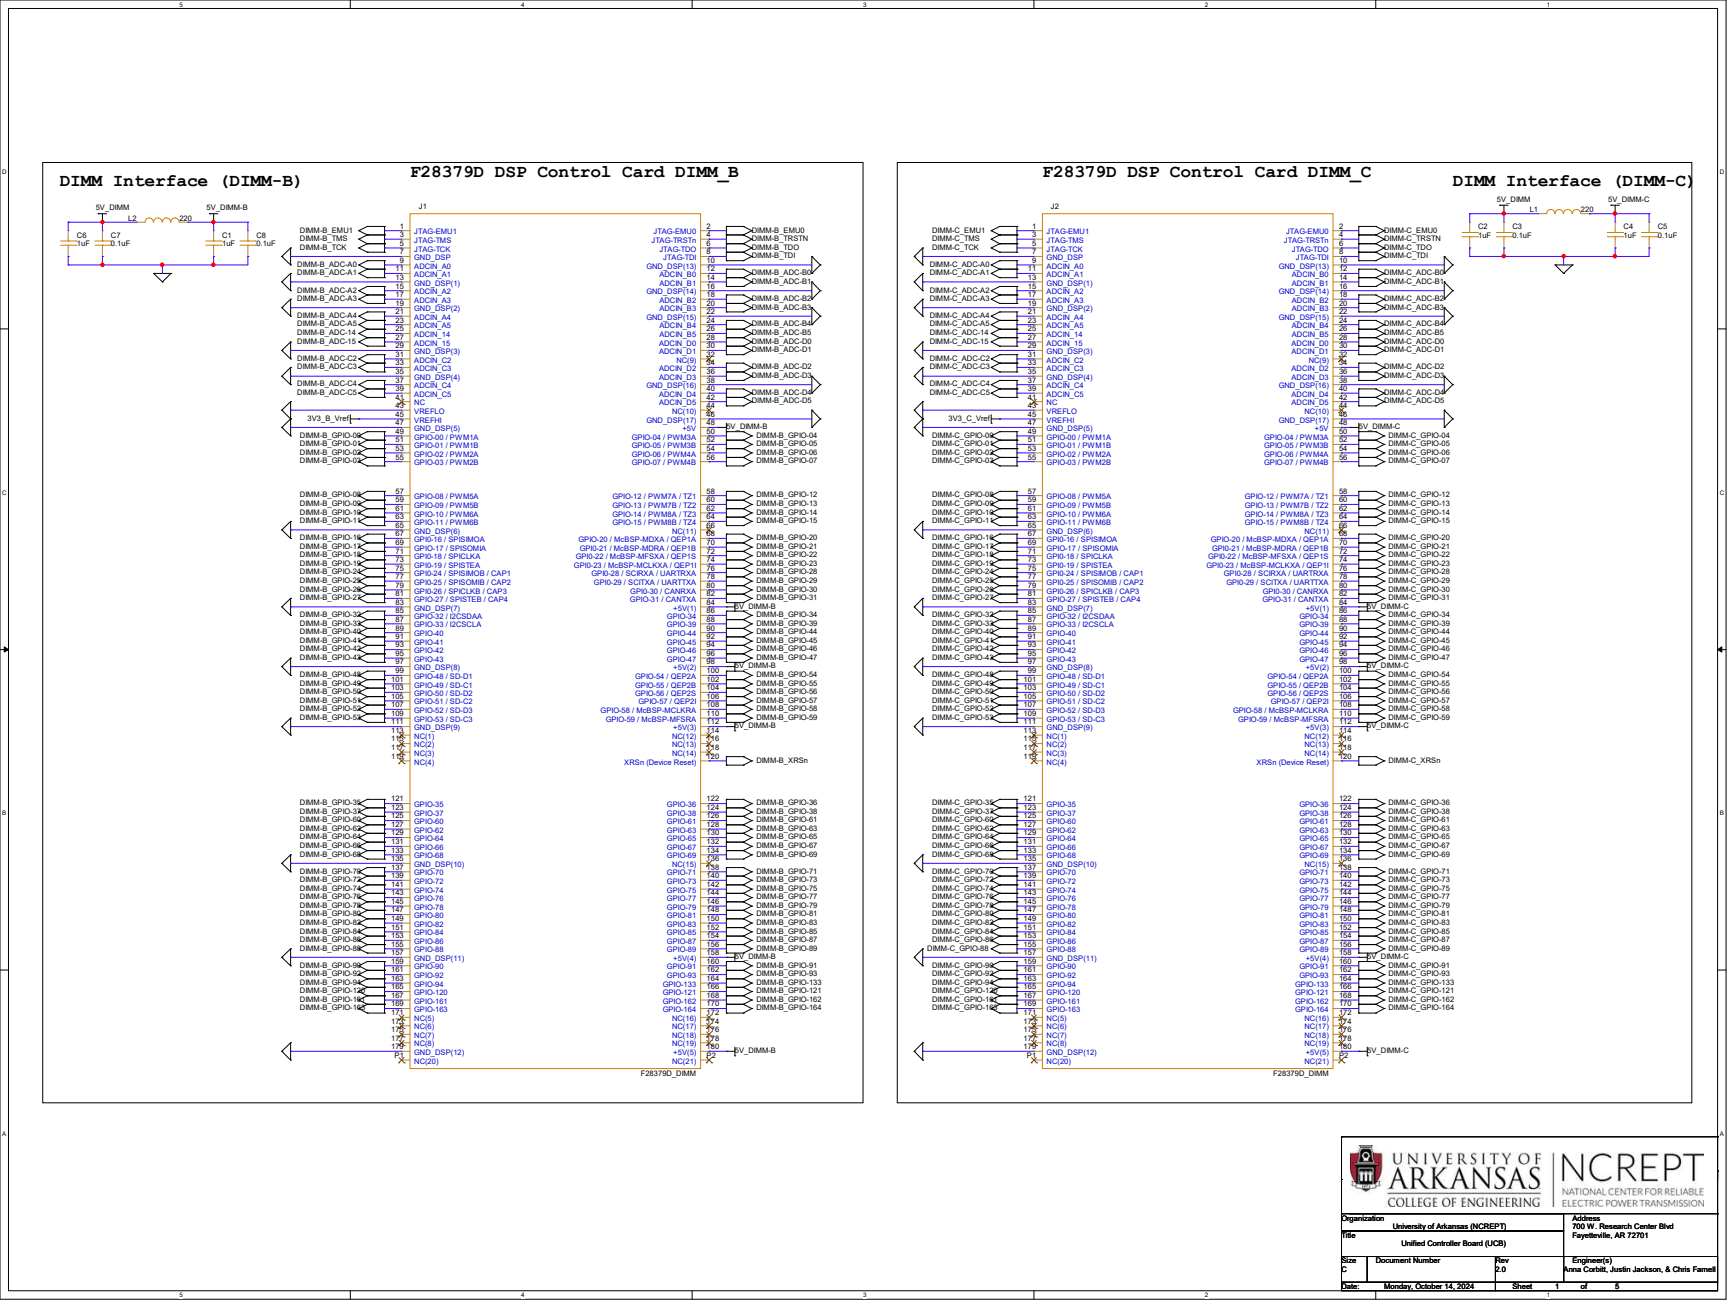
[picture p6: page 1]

5V_DIMM-B
DIMM-B_GPIO-12 DIMM-B_GPIO-13 DIMM-B_GPIO-14 DIMM-B_GPIO-15 DIMM-B_GPIO-20 DIMM-B_GPIO-21 DIMM-B_GPIO-22 DIMM-B_GPIO-23 DIMM-B_GPIO-28 DIMM-B_GPIO-29 DIMM-B_GPIO-30 DIMM-B_GPIO-31 DIMM-B_GPIO-34 DIMM-B_GPIO-39 DIMM-B_GPIO-44 DIMM-B_GPIO-45 DIMM-B_GPIO-46 DIMM-B_GPIO-47 DIMM-B_GPIO-55 DIMM-B_GPIO-54 DIMM-B_GPIO-56 DIMM-B_GPIO-57 DIMM-B_GPIO-58 DIMM-B_GPIO-59 DIMM-B_GPIO-36 DIMM-B_GPIO-38 DIMM-B_GPIO-61 DIMM-B_GPIO-63 DIMM-B_GPIO-65 DIMM-B_GPIO-67 DIMM-B_GPIO-69 DIMM-B_GPIO-71 DIMM-B_GPIO-73 DIMM-B_GPIO-75 DIMM-B_GPIO-77 DIMM-B_GPIO-79 DIMM-B_GPIO-81 DIMM-B_GPIO-83 DIMM-B_GPIO-85 DIMM-B_GPIO-87 DIMM-B_GPIO-89 DIMM-B_GPIO-91 DIMM-B_GPIO-93 DIMM-B_GPIO-133 DIMM-B_GPIO-121 DIMM-B_GPIO-162 DIMM-B_GPIO-164 DIMM-B_XRSn

# Mounting Holes

IDC Interface (IDC-A) | IDC Interface (IDC-B) | IDC Interface (IDC-C) | IDC Interface (IDC-D)

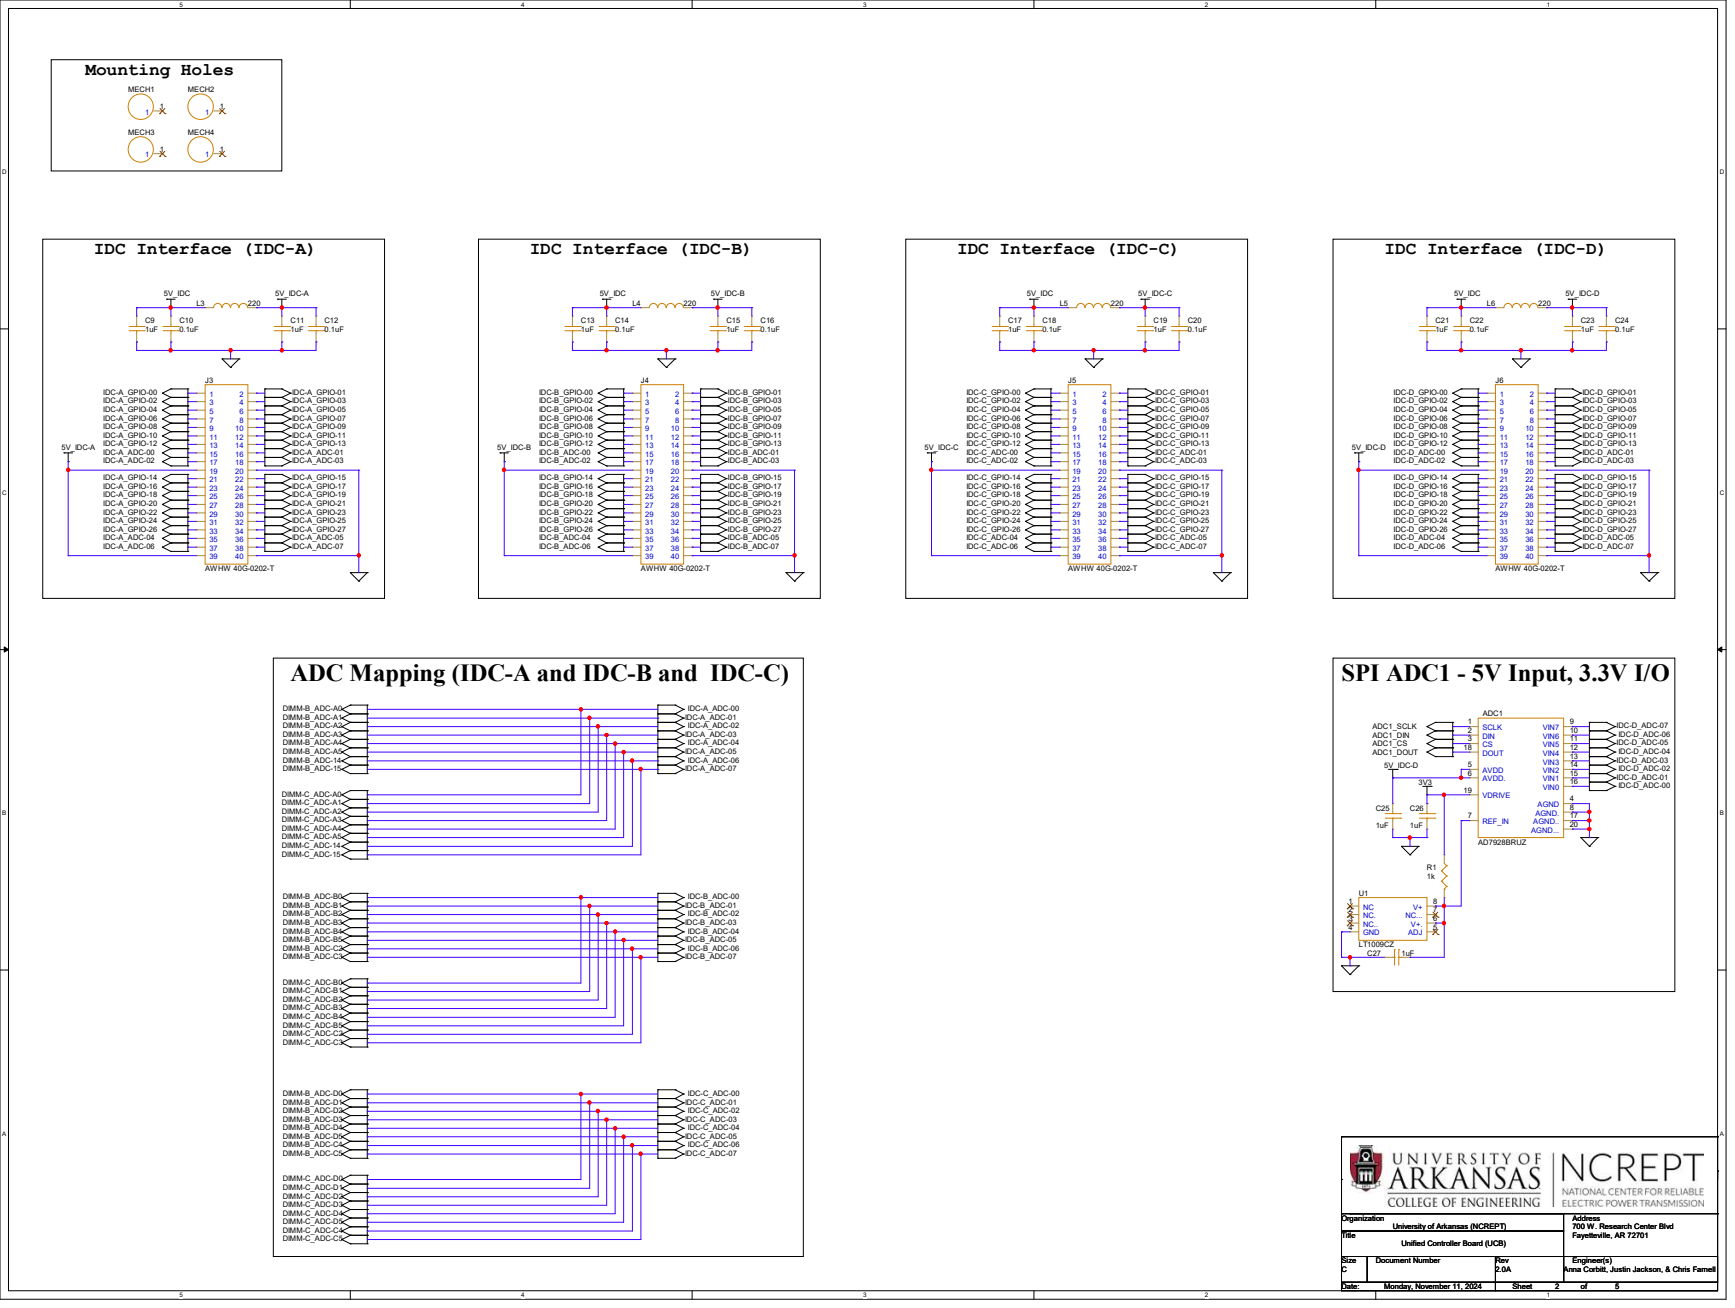
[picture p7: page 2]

CPLD/FPGA Bank_0 | CPLD/FPGA Bank_1 | CPLD/FPGA Bank_2
DIMM-C_GPIO-30 DIMM-C_GPIO-27 DIMM-C_GPIO-31 DIMM-C_GPIO-32 SPI_FLASH_MCLK DIMM-C_GPIO-33 SPI_FLASH_SPISO

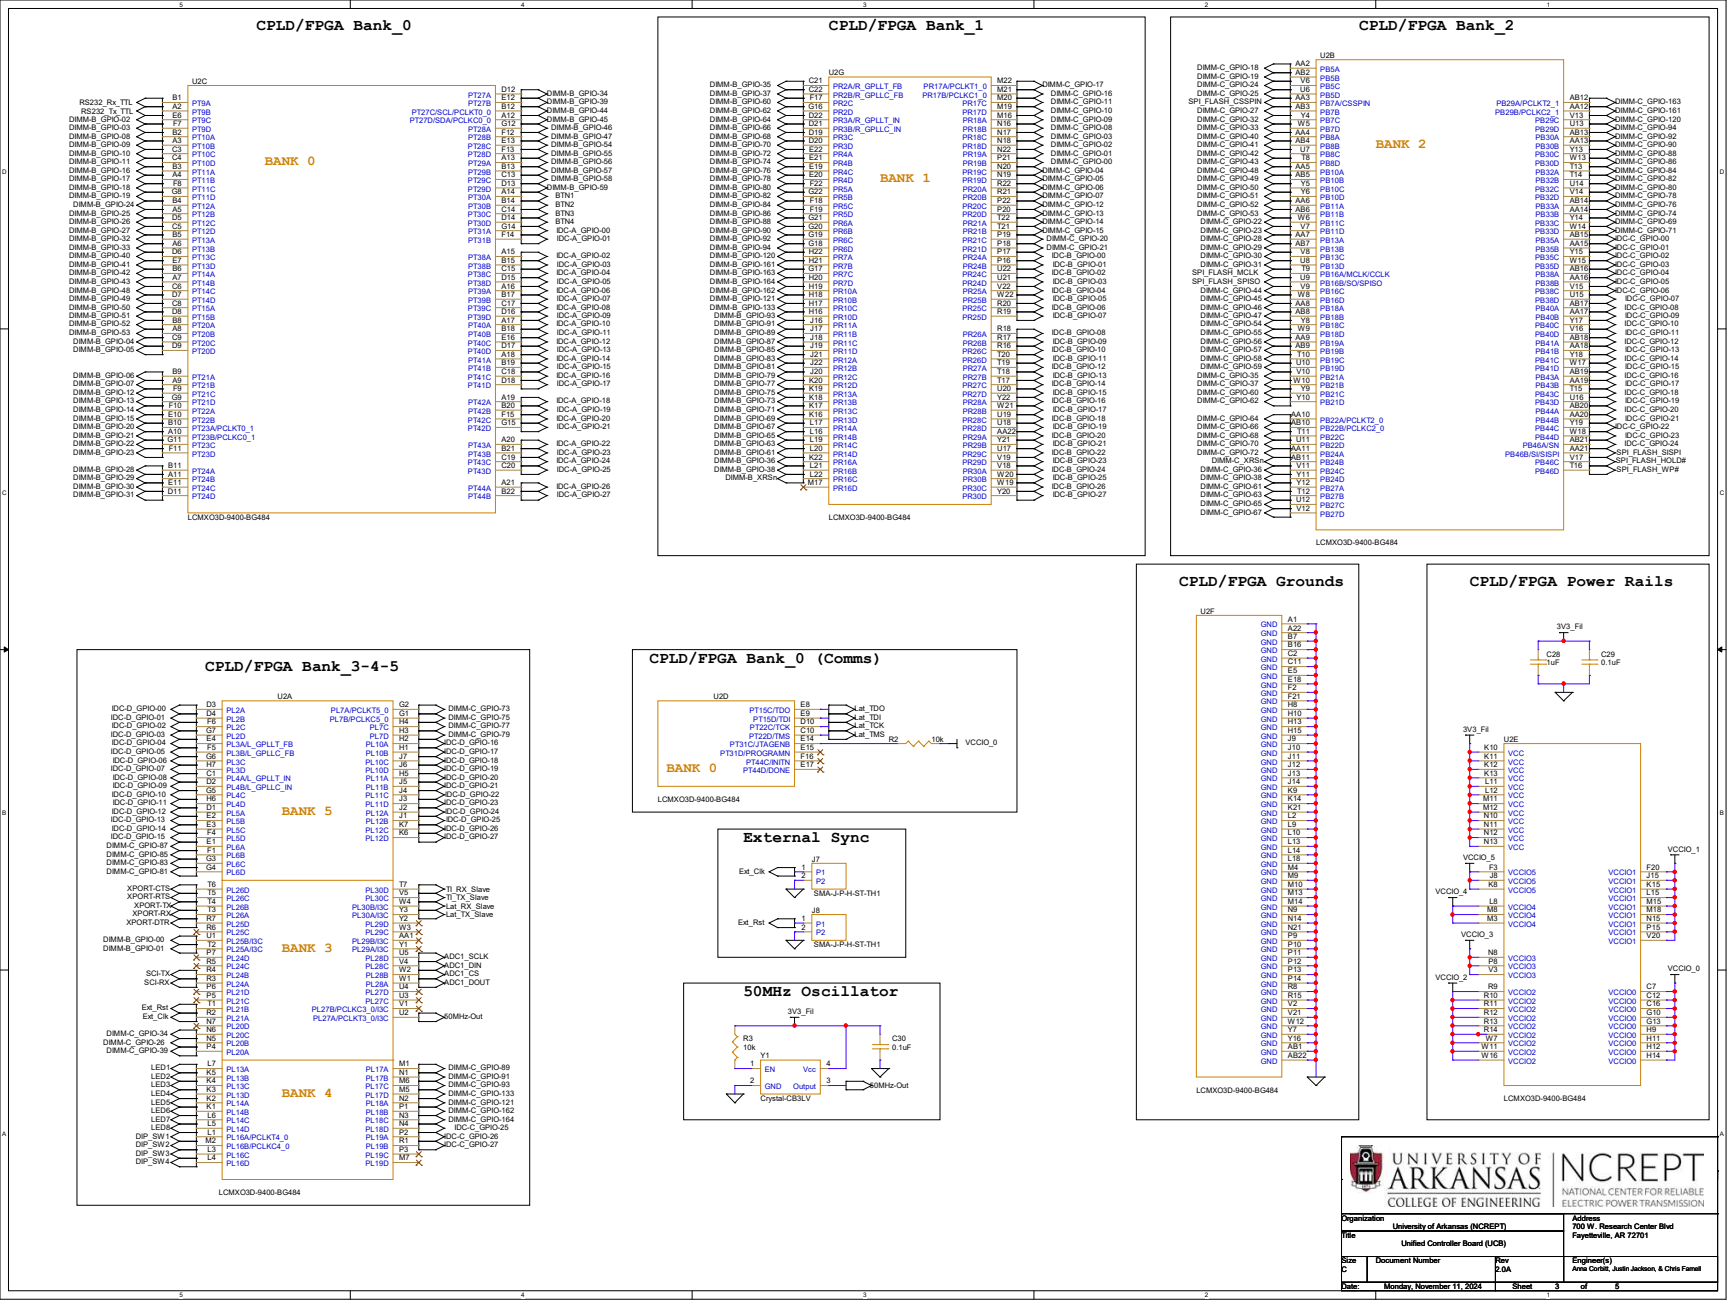
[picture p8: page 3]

CPLD/FPGA Bank_0 (Comms) CPLD/FPGA Bank_3-4-5

700 W. Research Center Blvd Fayetteville, AR 72701 University of Arkansas (NCREPT)

Anna Corbitt, Justin Jackson, & Chris Farnell

# USB Input and TVS

# FTDI Chip (JTAG Interface [Lattice])

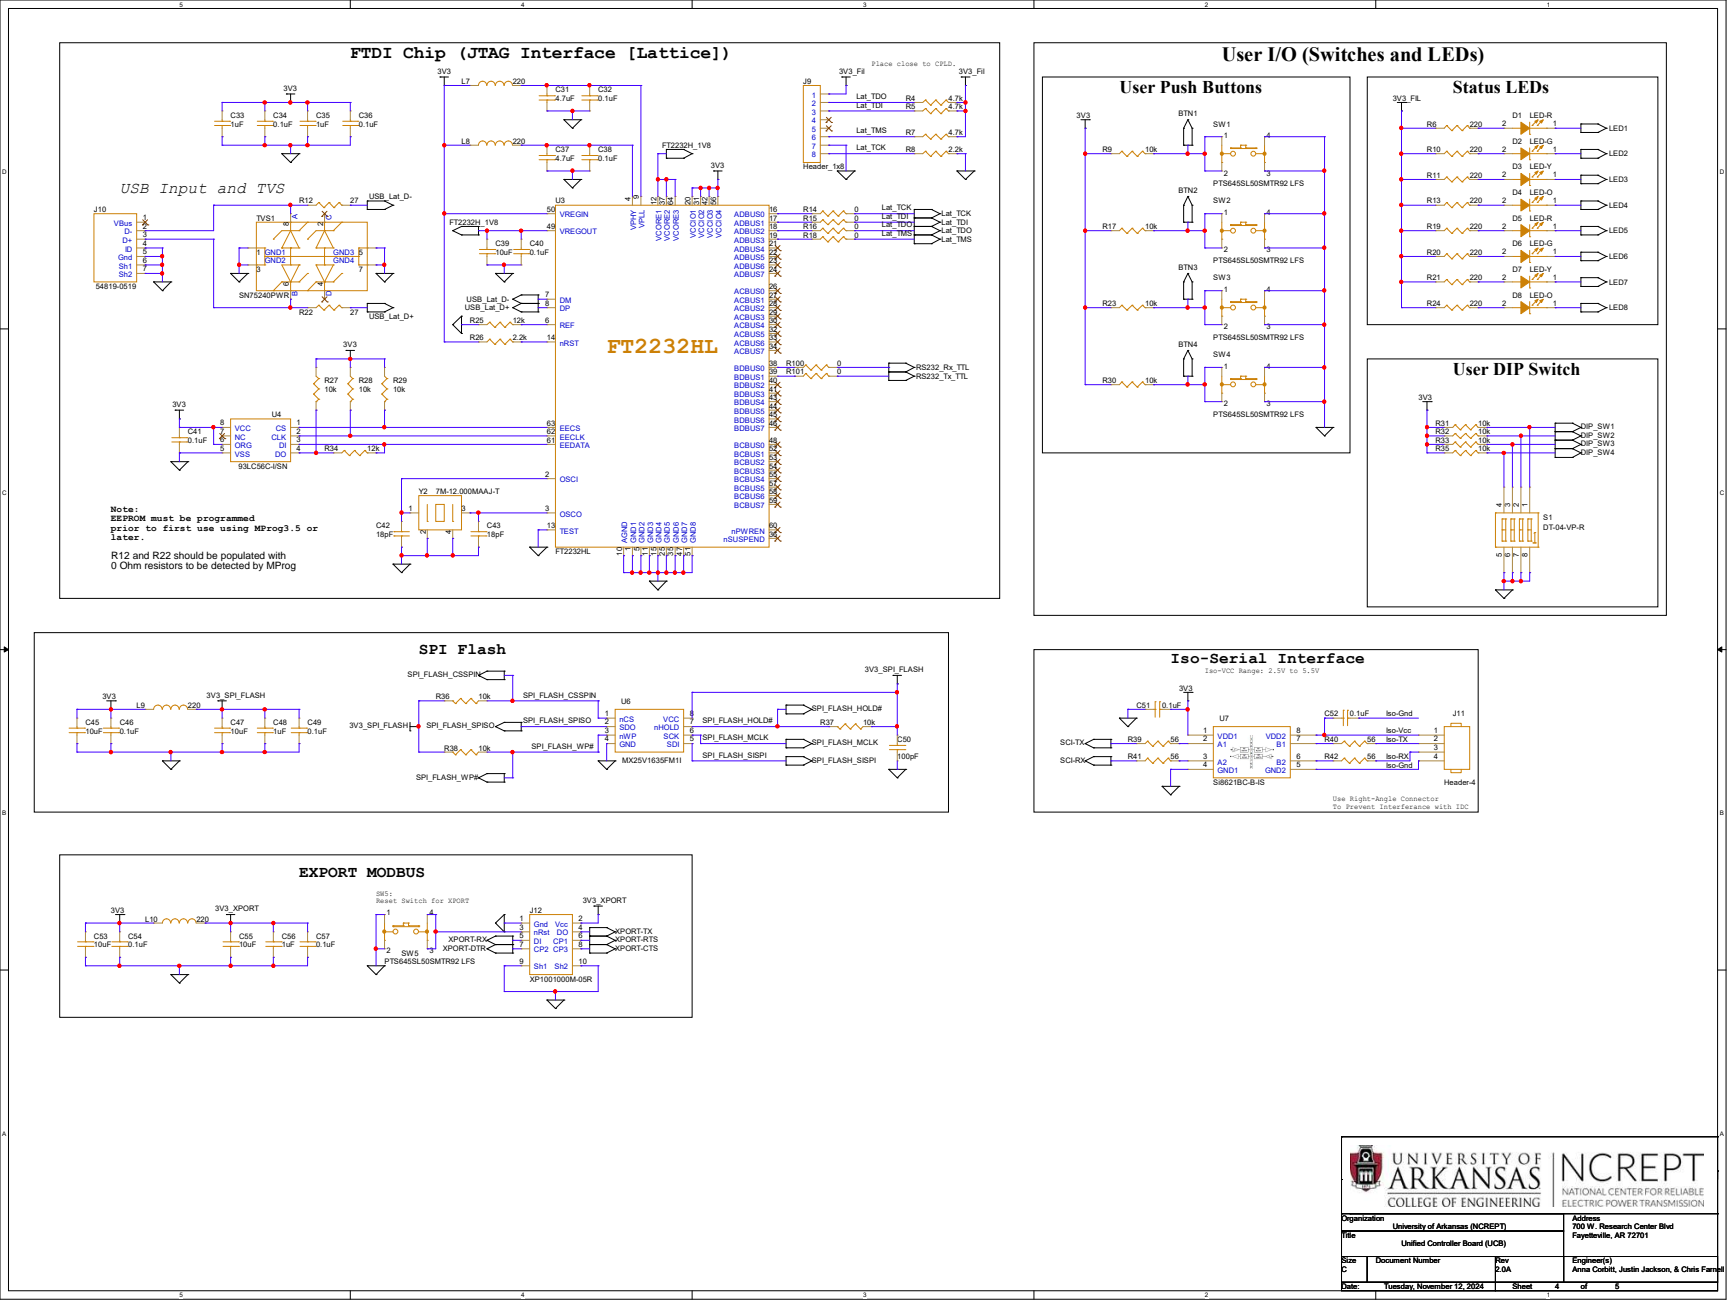
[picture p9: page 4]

User I/O (Switches and LEDs)

Place close to CPLD.
J9Header_1x8

Note:
EEPROM must be programmed
prior to first use using MProg3.5 or
later.
R12 and R22 should be populated with
0 Ohm resistors to be detected by MProg

Iso-Serial Interface Iso-VCC Range: 2.5V to 5.5V

Use Right-Angle Connector
To Prevent Interferance with IDC

# 9-36Vdc to 5V/3.3V/1.8V Converter (Digital)

# DC Power Entry (9V-36V)

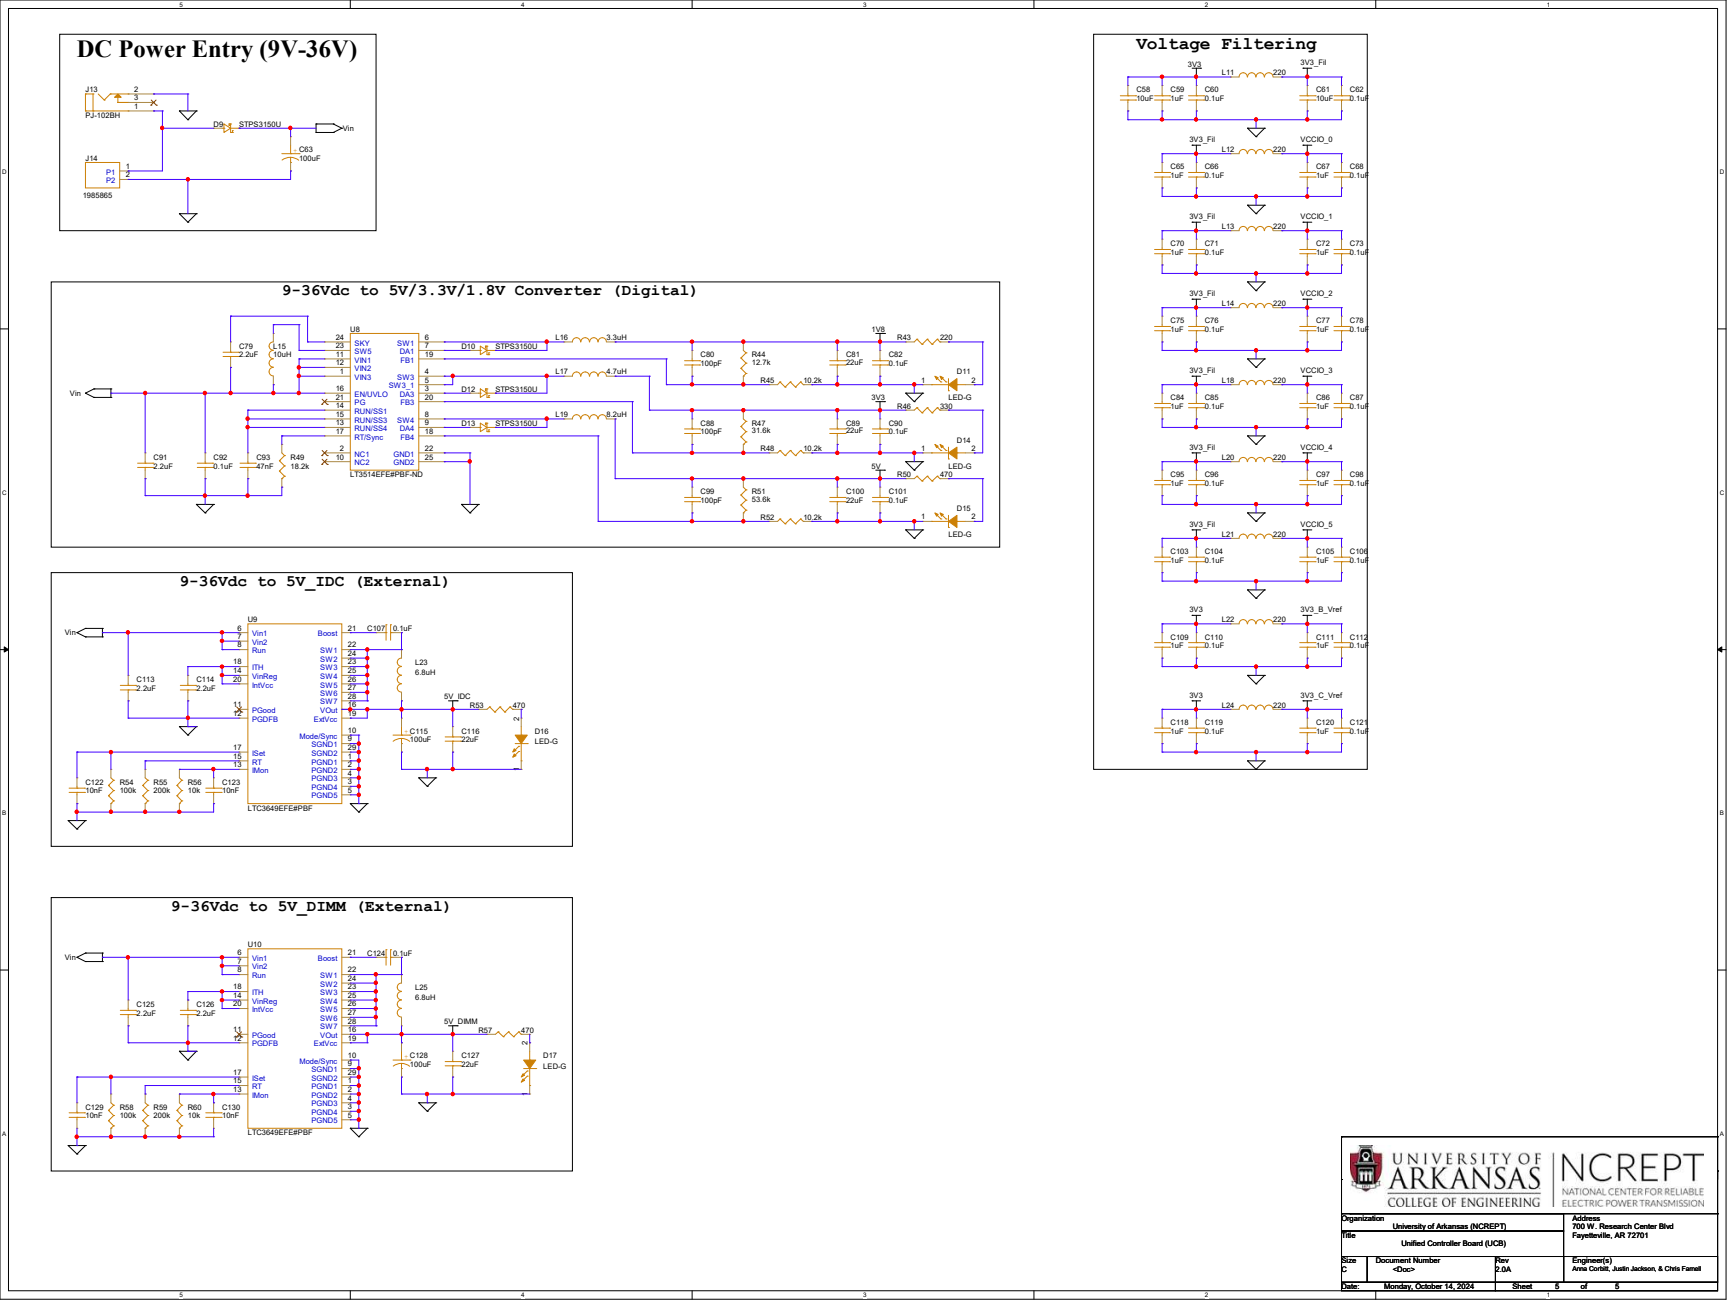
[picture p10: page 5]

Voltage Filtering Vin Vin

700 W. Research Center Blvd Fayetteville, AR 72701 University of Arkansas (NCREPT)

Anna Corbitt, Justin Jackson, & Chris Farnell

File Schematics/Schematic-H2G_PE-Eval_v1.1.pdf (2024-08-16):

# Isolated 3.3V/5V Supplies

# Isolated Voltage Sensing

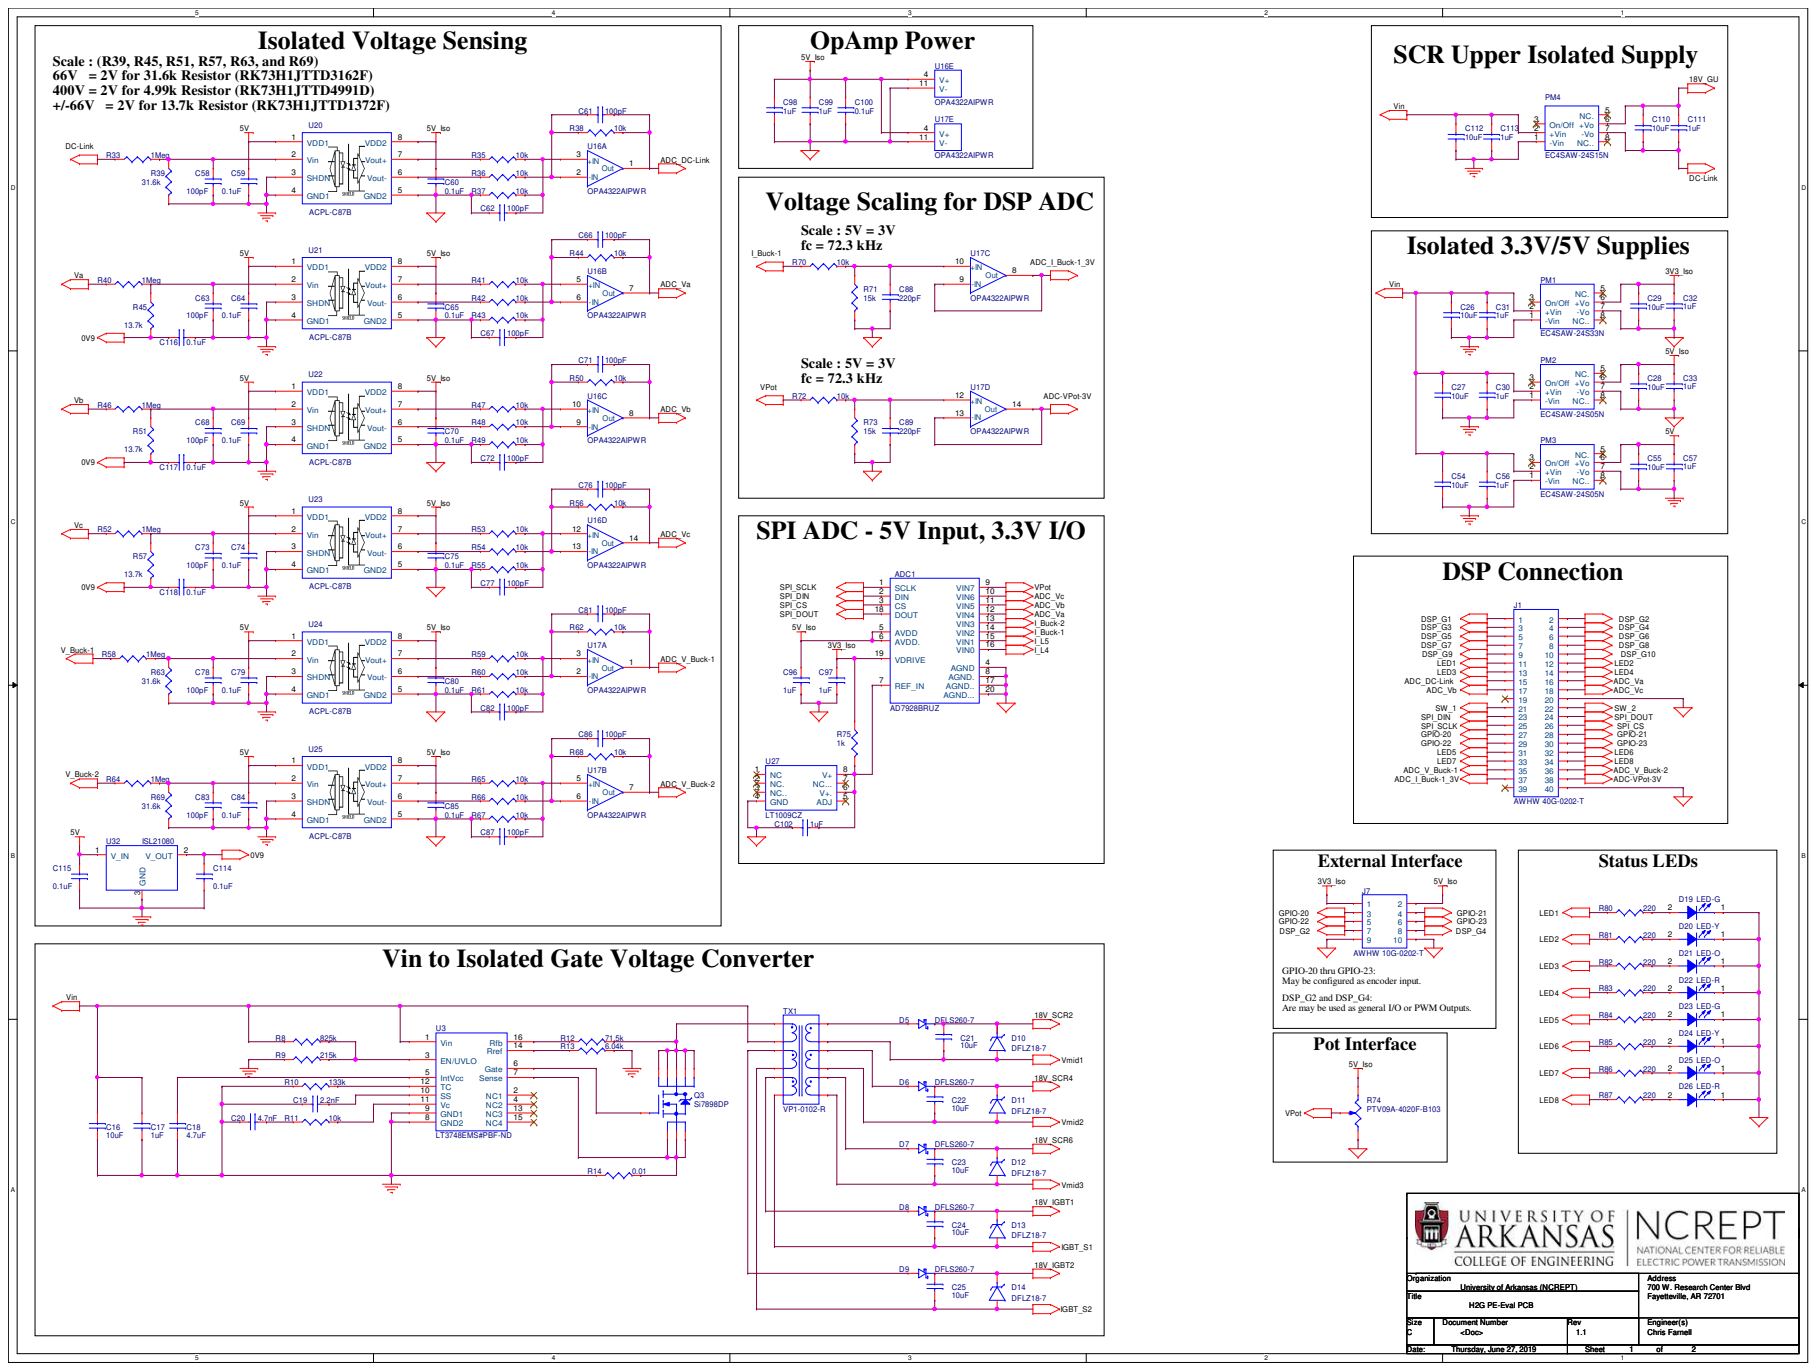
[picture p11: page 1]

SCR Upper Isolated Supply

Voltage Scaling for DSP ADC

Vin to Isolated Gate Voltage Converter

GPIO-20 thru GPIO-23:
May be configured as encoder input.
DSP_G2 and DSP_G4:
Are may be used as general I/O or PWM Outputs.

University of Arkansas (NCREPT)

# Buck Converter 1 (50V Max)

# DC Power Entry (9V-36V)

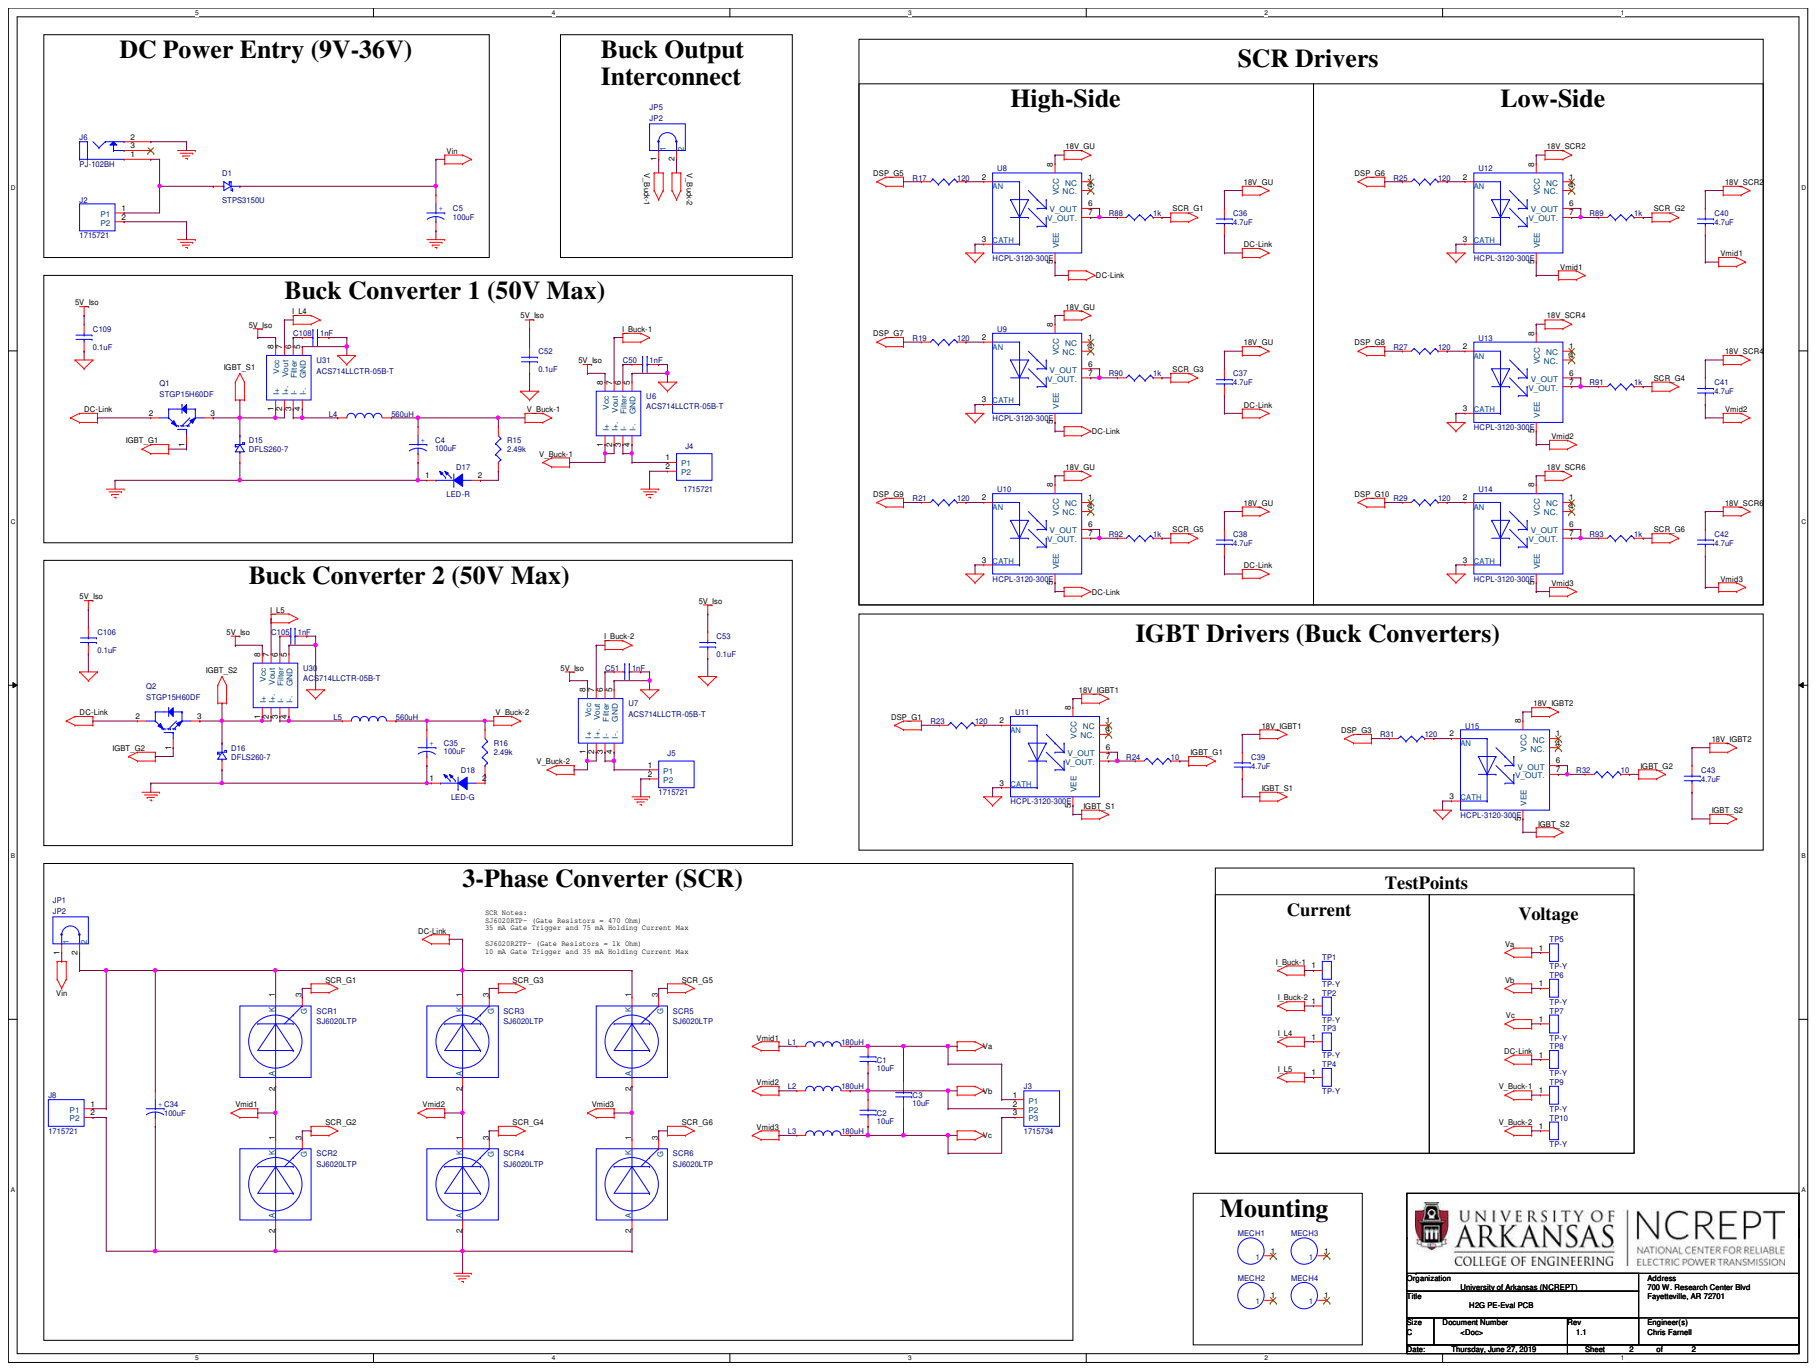
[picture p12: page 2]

DC-Link
IGBT Drivers (Buck Converters)

SCR Notes:
SJ6020RTP- (Gate Resistors = 470 Ohm)
35 mA Gate Trigger and 75 mA Holding Current Max

SJ6020R2TP- (Gate Resistors = 1k Ohm)
10 mA Gate Trigger and 35 mA Holding Current Max

University of Arkansas (NCREPT)

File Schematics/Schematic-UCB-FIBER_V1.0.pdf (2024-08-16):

# Fiber Optic Interface RX/TX

# Fiber Optic TX Drivers

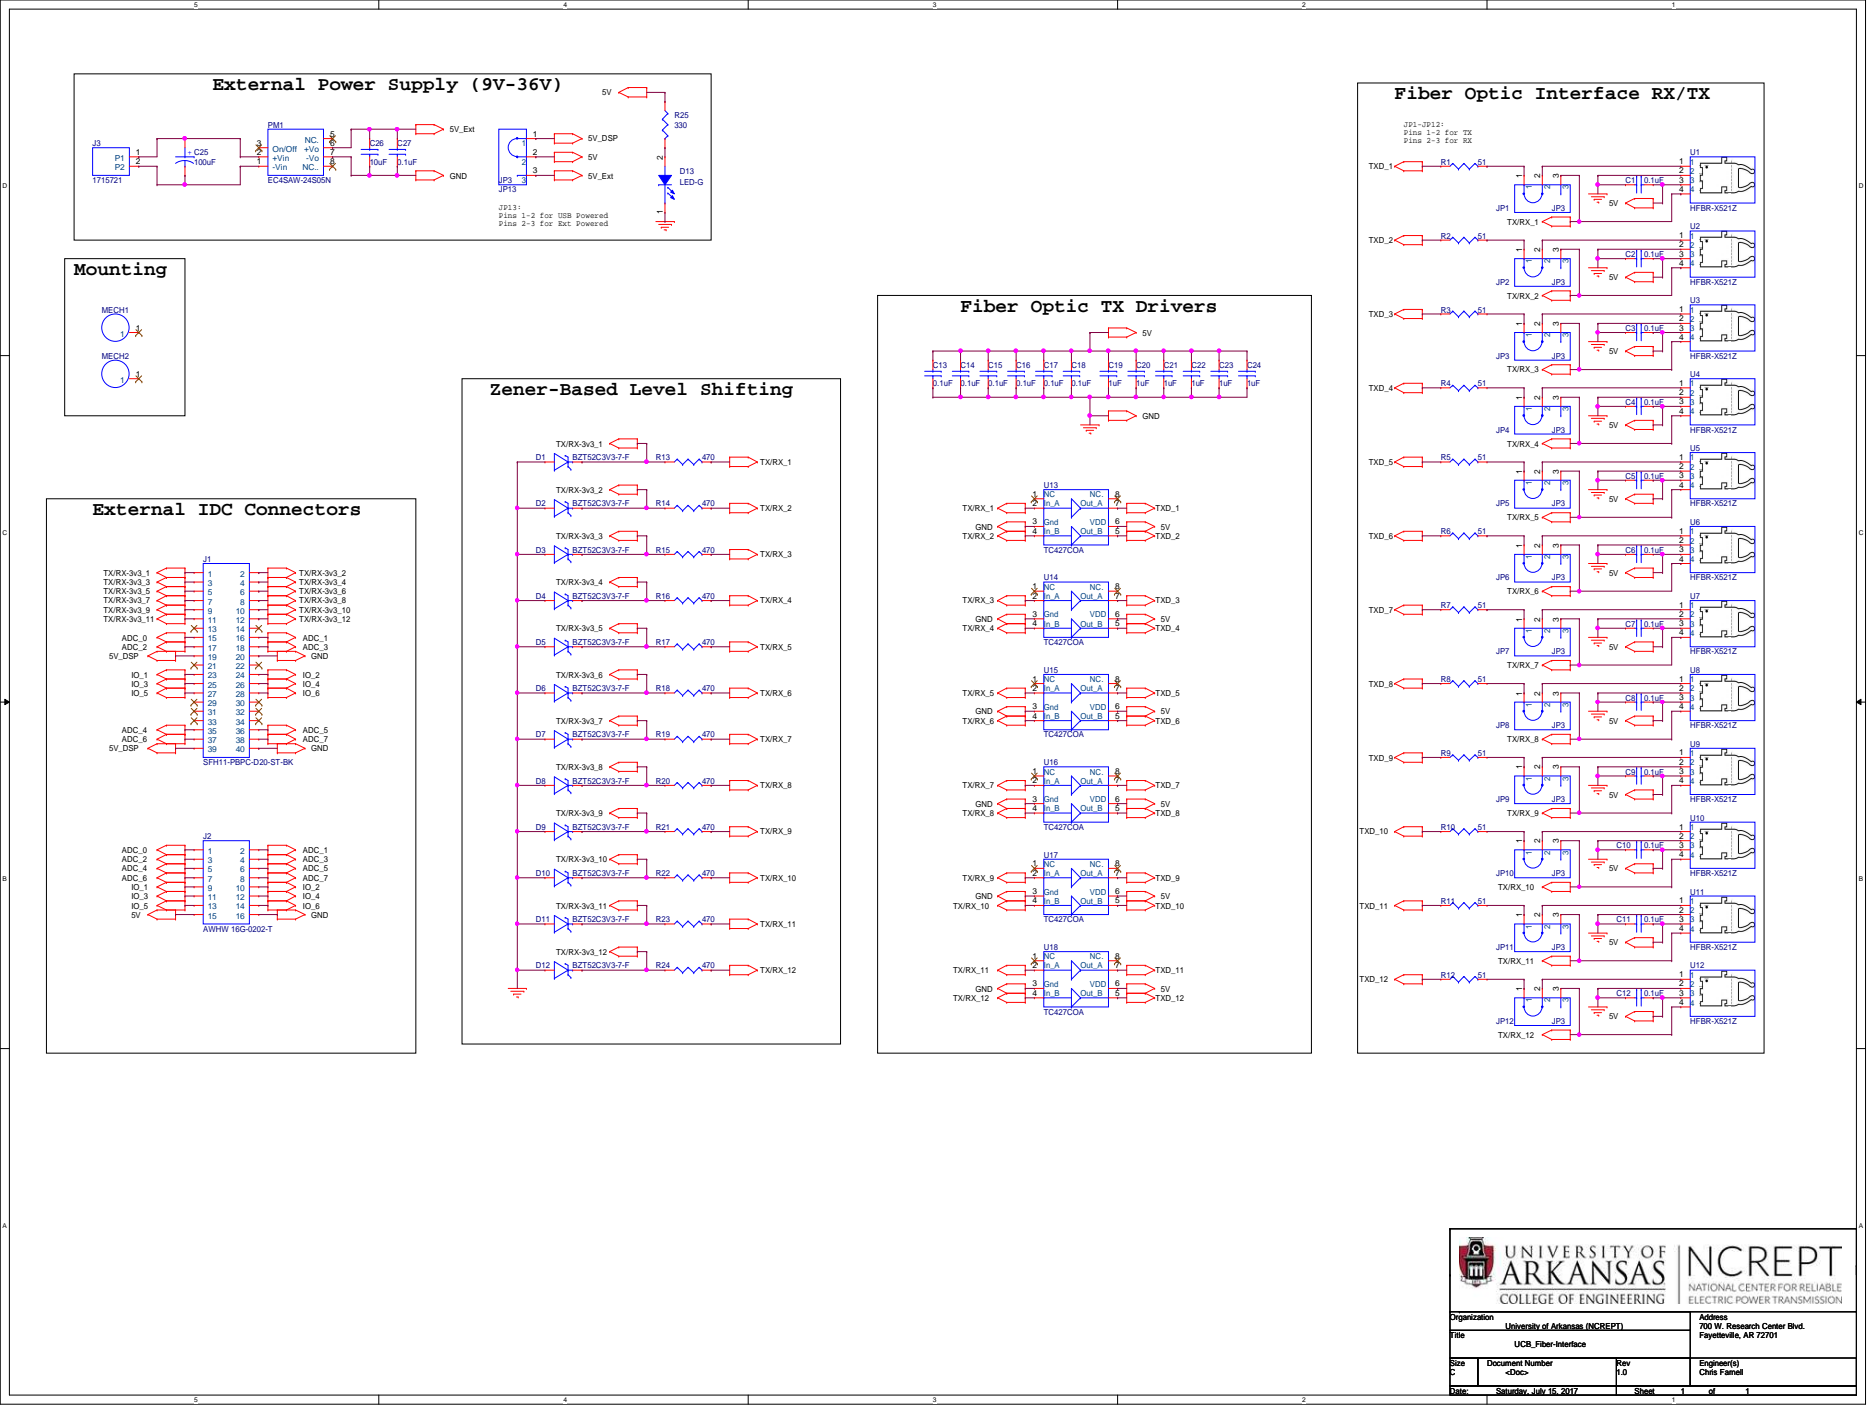
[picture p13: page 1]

Pins 1-2 for USB Powered
Pins 2-3 for Ext Powered

Zener-Based Level Shifting

University of Arkansas (NCREPT)

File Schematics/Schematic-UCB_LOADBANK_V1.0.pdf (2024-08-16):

DC Power Entry (12V) | Mounting

# DSP Connection

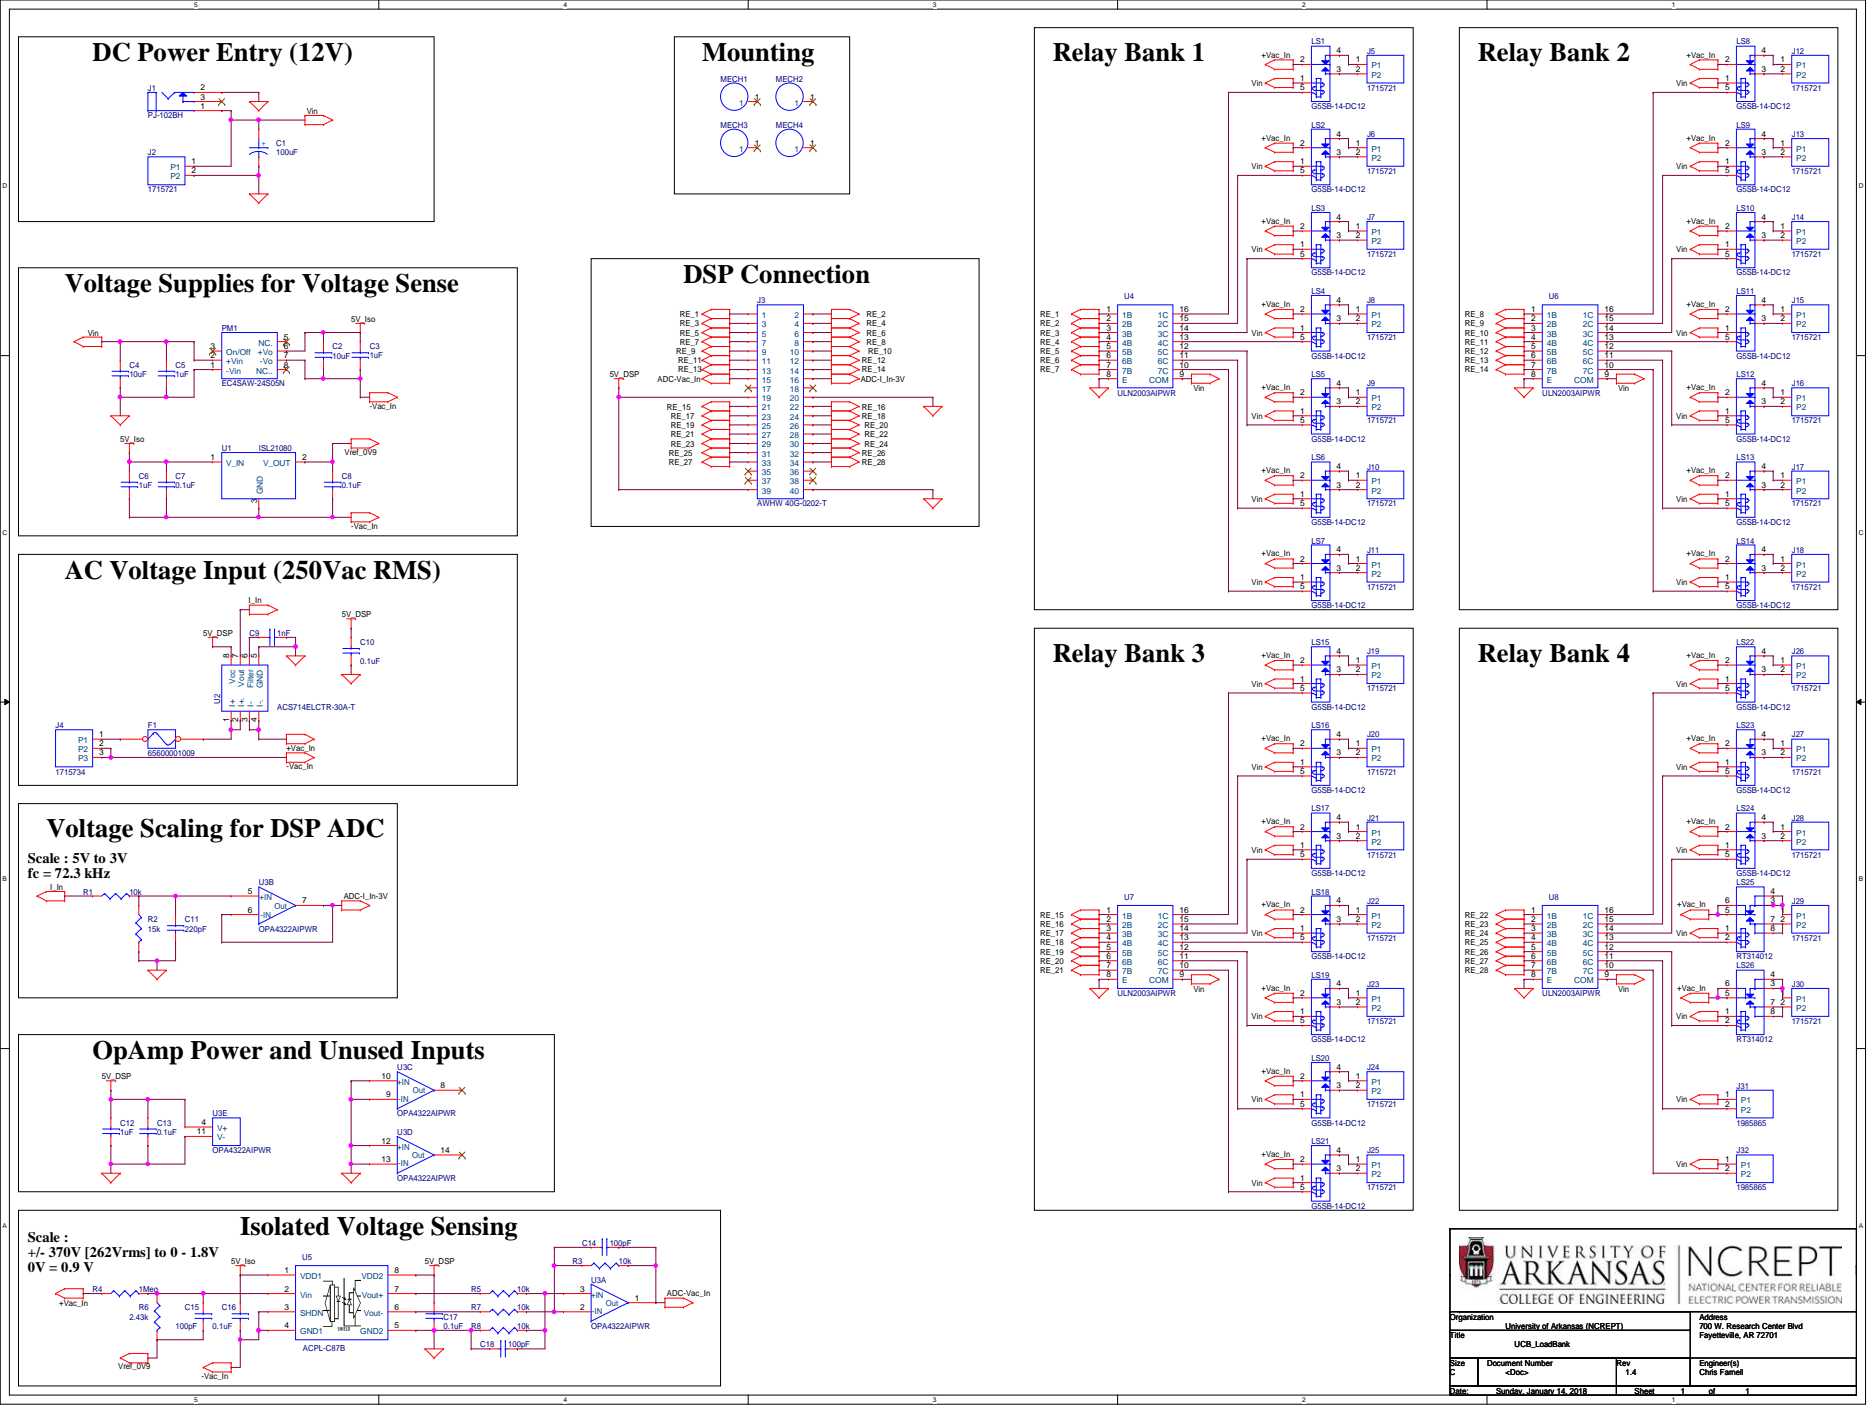
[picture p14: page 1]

Voltage Supplies for Voltage Sense

AC Voltage Input (250Vac RMS)

OpAmp Power and Unused Inputs

Isolated Voltage Sensing Scale :

University of Arkansas (NCREPT)

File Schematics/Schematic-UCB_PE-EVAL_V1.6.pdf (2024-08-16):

# Isolated Voltage Sensing

## Scale : (R39, R45, R51, R57, R63, and R69)

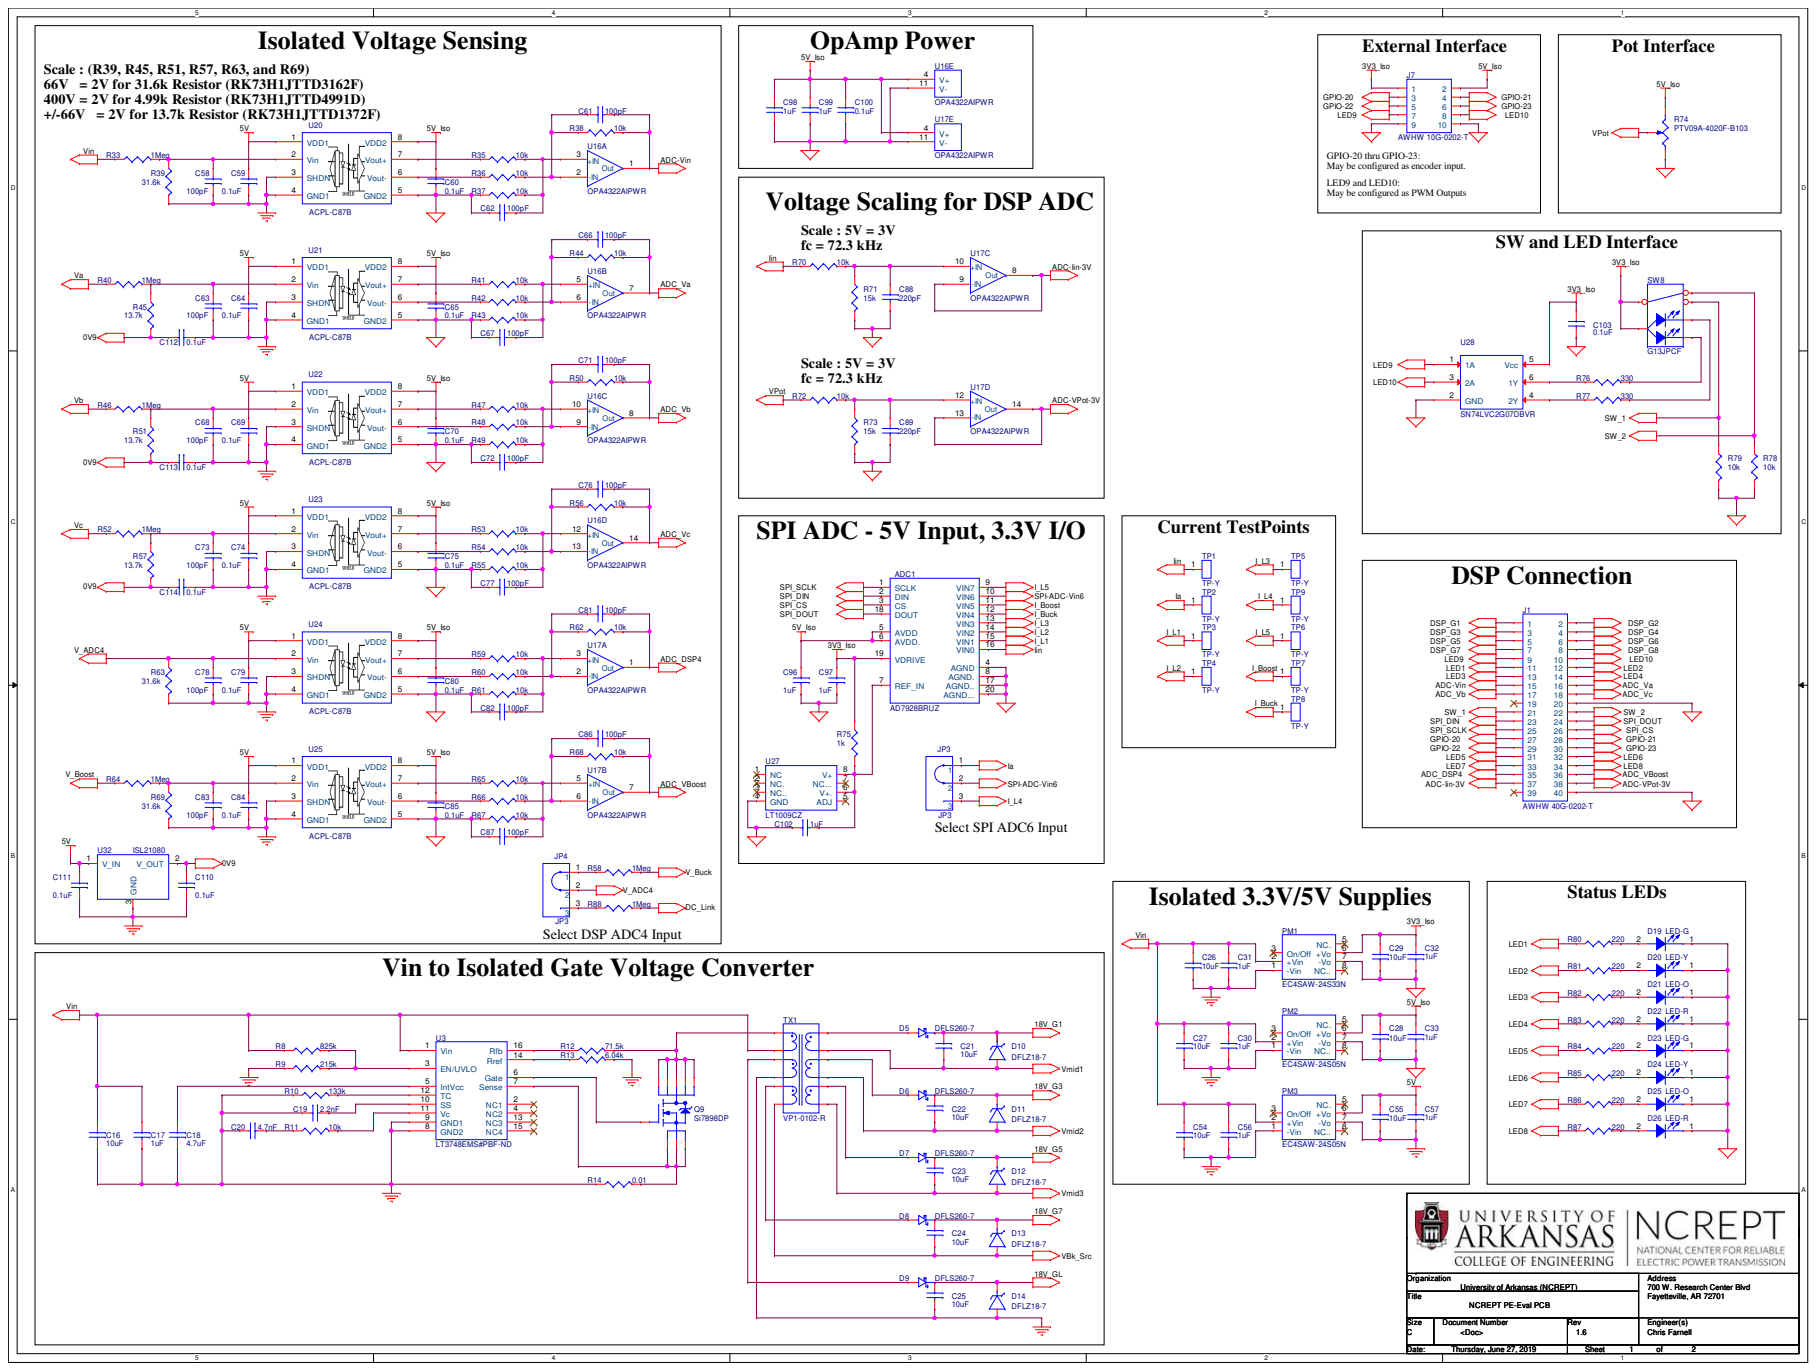
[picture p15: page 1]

GPIO-20 thru GPIO-23:
May be configured as encoder input.
LED9 and LED10:
May be configured as PWM Outputs

Voltage Scaling for DSP ADC

SW and LED Interface

Vin to Isolated Gate Voltage Converter

University of Arkansas (NCREPT)

NCREPT PE-Eval PCB

# Buck Converter (50V Max)

# DC Power Entry (9V-36V)

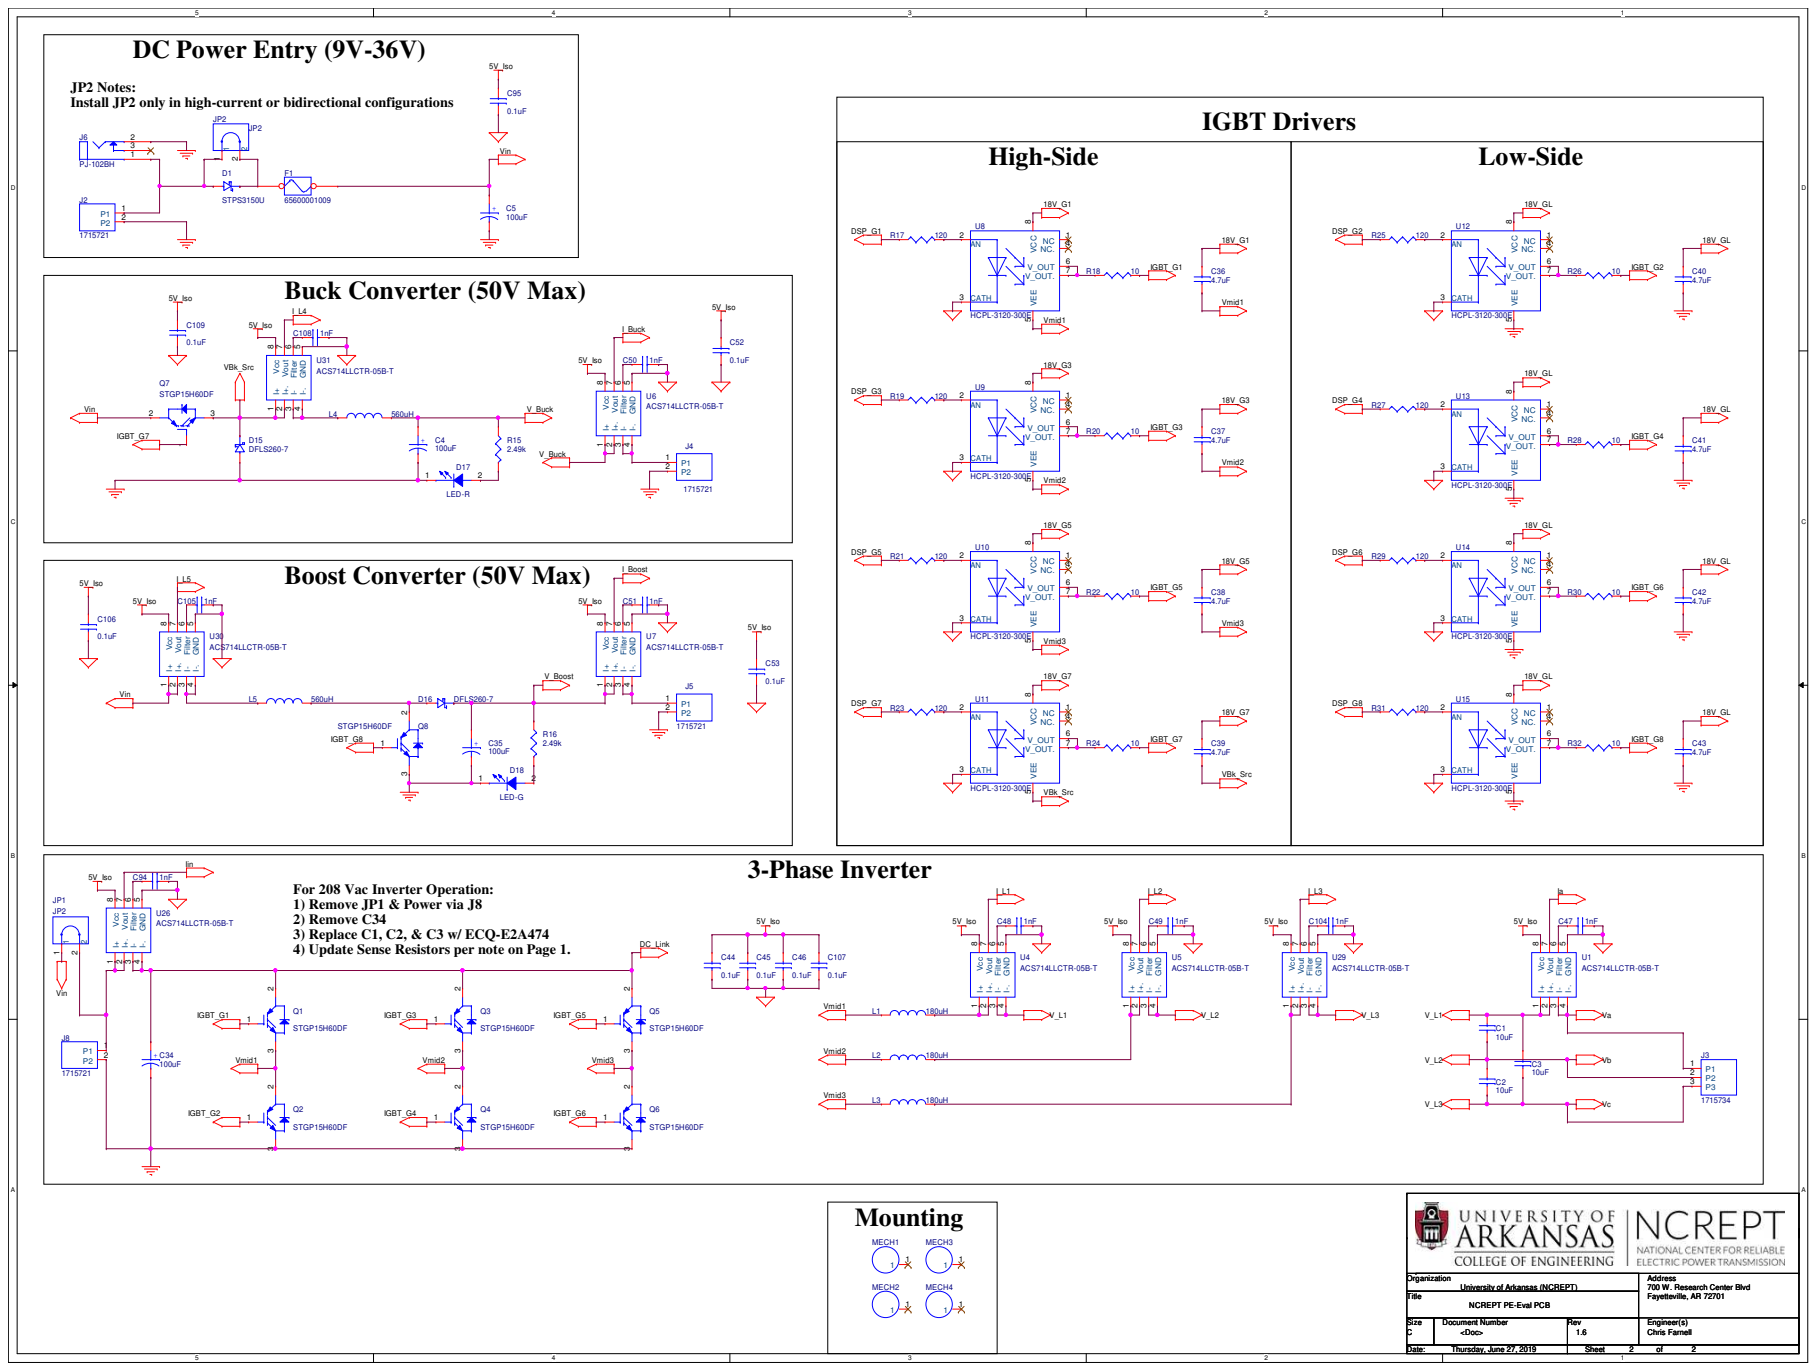
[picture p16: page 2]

JP2 Notes:
Install JP2 only in high-current or bidirectional configurations

For 208 Vac Inverter Operation:
1) Remove JP1 & Power via J8
2) Remove C34
3) Replace C1, C2, & C3 w/ ECQ-E2A474

4) Update Sense Resistors per note on Page 1.

University of Arkansas (NCREPT)

NCREPT PE-Eval PCB

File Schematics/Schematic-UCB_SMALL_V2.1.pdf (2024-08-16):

# Ext Voltage Outputs

# Mounting Holes Power Input and Supplies

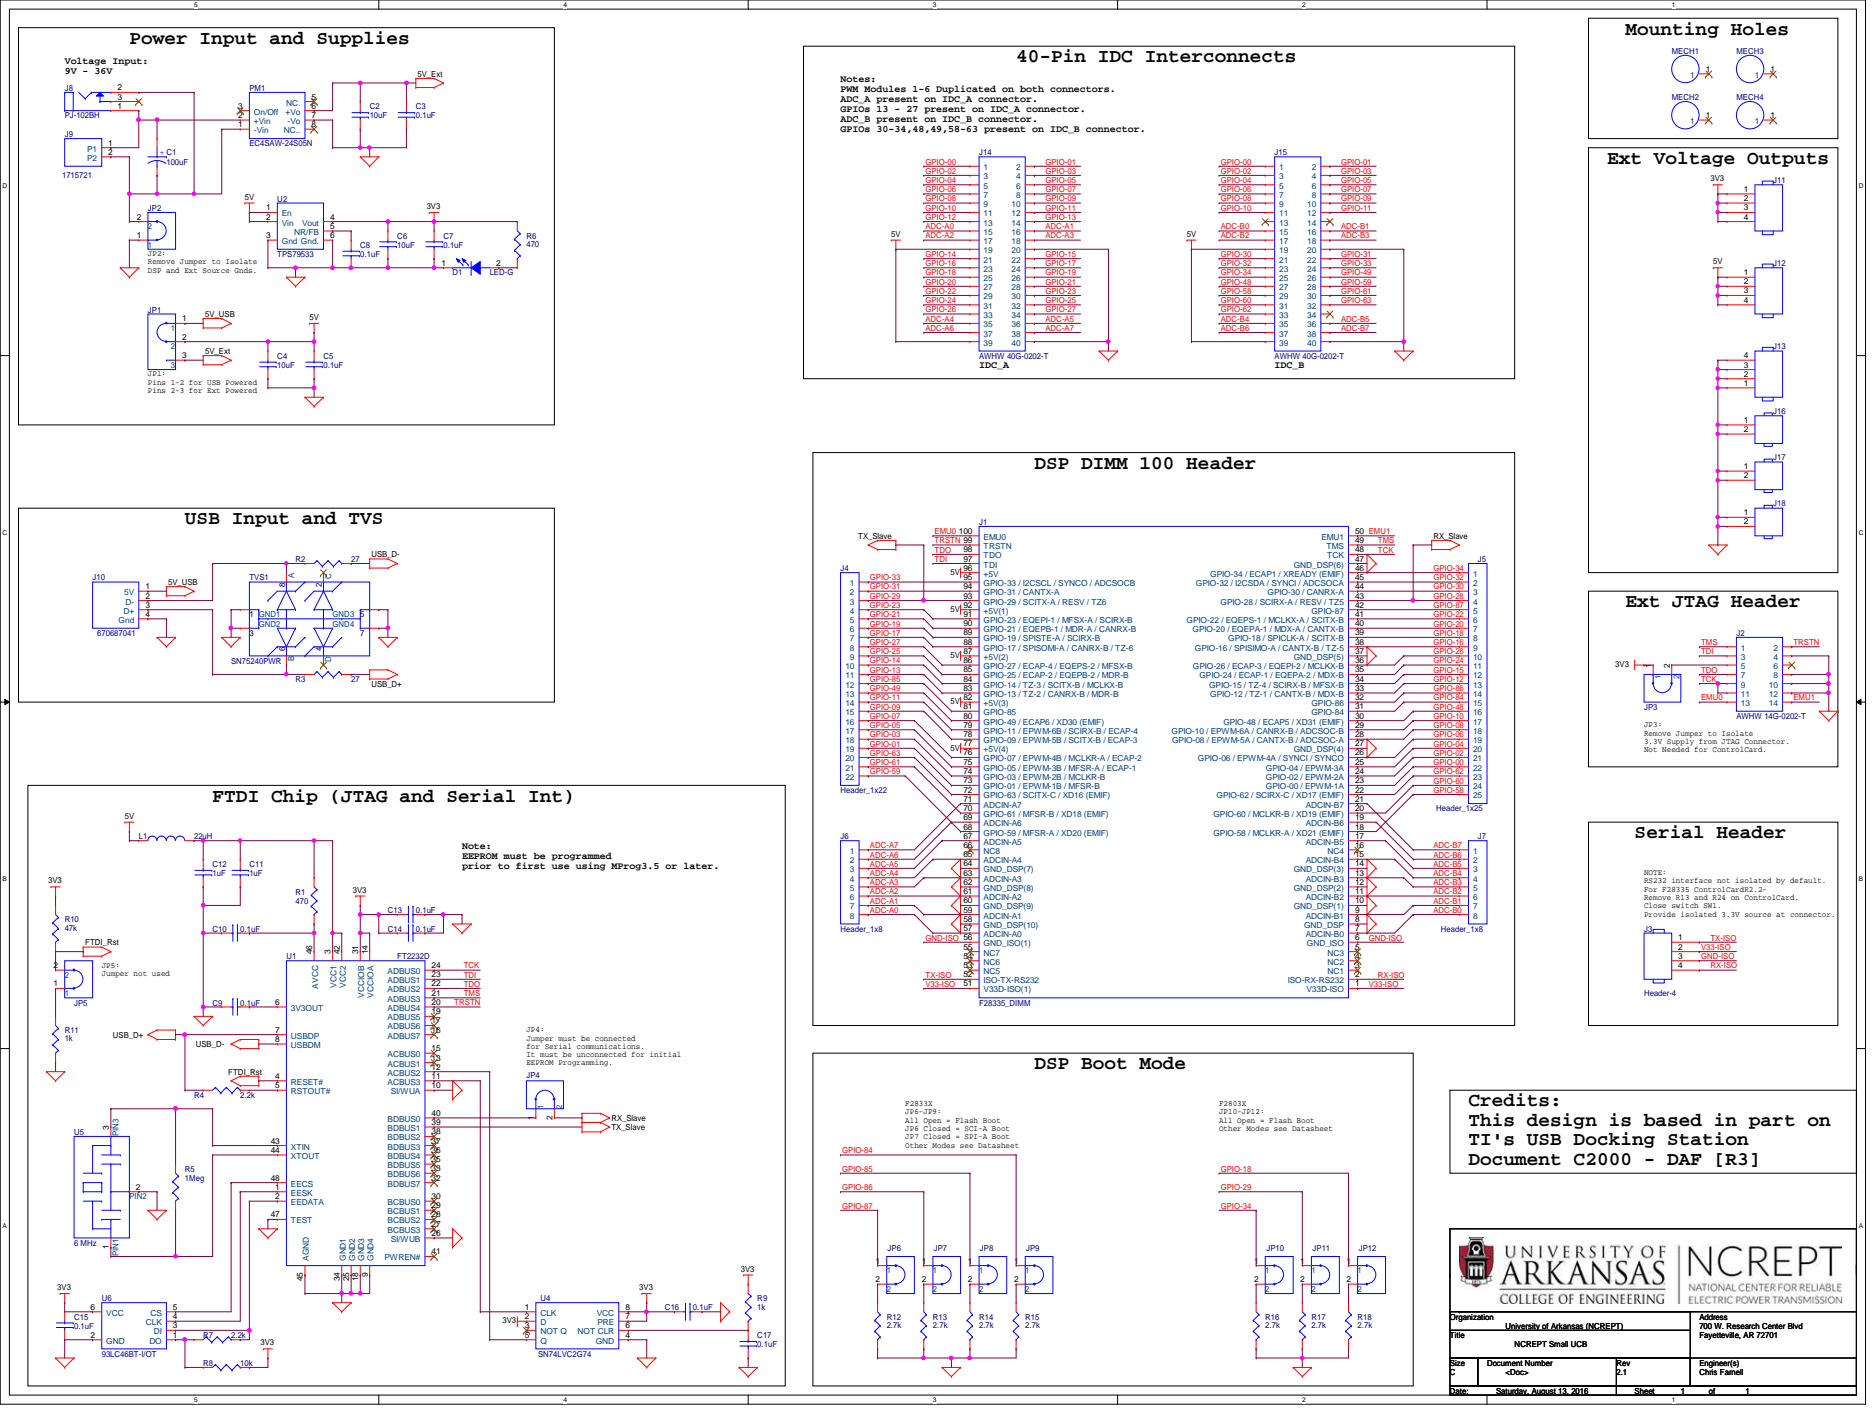
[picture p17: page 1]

Notes:
PWM Modules 1-6 Duplicated on both connectors.
ADC_A present on IDC_A connector.
GPIOs 13 - 27 present on IDC_A connector.
ADC_B present on IDC_B connector.
GPIOs 30-34,48,49,58-63 present on IDC_B connector.

GPIO-14
GPIO-16
GPIO-18
GPIO-20
GPIO-22
GPIO-24
GPIO-26
ADC-A6
V33D-ISO(1) 51 ISO-TX-RS232 52 NC5 53 NC6 54 NC7 55 GND_ISO(1) 56 ADCIN-A0 57 GND_DSP(10) 58 ADCIN-A1 59 GND_DSP(9) 60 ADCIN-A2 61 GND_DSP(8) 62 ADCIN-A3 63 GND_DSP(7) 64 ADCIN-A4 65 NC8 66 ADCIN-A5 67 GPIO-59 / MFSR-A / XD20 (EMIF) 68 ADCIN-A6 69 GPIO-61 / MFSR-B / XD18 (EMIF) 70 ADCIN-A7 71 GPIO-63 / SCITX-C / XD16 (EMIF) 72 GPIO-01 / EPWM-1B / MFSR-B 73 GPIO-03 / EPWM-2B / MCLKR-B 74 GPIO-05 / EPWM-3B / MFSR-A / ECAP-1 75 GPIO-07 / EPWM-4B / MCLKR-A / ECAP-2 76 +5V(4) 77 GPIO-09 / EPWM-5B / SCITX-B / ECAP-3 78 GPIO-11 / EPWM-6B / SCIRX-B / ECAP-4 79 GPIO-49 / ECAP6 / XD30 (EMIF) 80 GPIO-85 81 +5V(3) 82 GPIO-13 / TZ-2 / CANRX-B / MDR-B 83 GPIO-14 / TZ-3 / SCITX-B / MCLKX-B 84 GPIO-25 / ECAP-2 / EQEPB-2 / MDR-B 85 GPIO-27 / ECAP-4 / EQEPS-2 / MFSX-B 86 +5V(2) 87 GPIO-17 / SPISOMI-A / CANRX-B / TZ-6 88 GPIO-19 / SPISTE-A / SCIRX-B 89 GPIO-21 / EQEPB-1 / MDR-A / CANRX-B 90 GPIO-23 / EQEPI-1 / MFSX-A / SCIRX-B 91 +5V(1) 92 GPIO-29 / SCITX-A / RESV / TZ6 93 GPIO-31 / CANTX-A 94 GPIO-33 / I2CSCL / SYNCO / ADCSOCB 95 +5V 96 TDI 97 TDO 98 TRSTN 99 EMU0 100
EMU0

USB Input and TVS

GPIO-32 / I2CSDA / SYNCI / ADCSOCA 4445 GPIO-34 / ECAP1 / XREADY (EMIF)

GPIO-28 / SCIRX-A / RESV / TZ5 4243 GPIO-30 / CANRX-A

GPIO-20 / EQEPA-1 / MDX-A / CANTX-B 3940 GPIO-22 / EQEPS-1 / MCLKX-A / SCITX-B

GPIO-16 / SPISIMO-A / CANTX-B / TZ-5 3738 GPIO-18 / SPICLK-A / SCITX-B

GPIO-24 / ECAP-1 / EQEPA-2 / MDX-B 3435 GPIO-26 / ECAP-3 / EQEPI-2 / MCLKX-B

GPIO-12 / TZ-1 / CANTX-B / MDX-B 3233 GPIO-15 / TZ-4 / SCIRX-B / MFSX-B

GPIO-08 / EPWM-5A / CANTX-B / ADCSOC-A 2728 GPIO-10 / EPWM-6A / CANRX-B / ADCSOC-B

Remove Jumper to Isolate
3.3V Supply from JTAG Connector.
Not Needed for ControlCard.

GPIO-04 / EPWM-3A 2425 GPIO-06 / EPWM-4A / SYNCI / SYNCO

FTDI Chip (JTAG and Serial Int)

GPIO-00 / EPWM-1A 2223 GPIO-02 / EPWM-2A

GPIO-62 / SCIRX-C / XD17 (EMIF) 21
GPIO-60 / MCLKR-B / XD19 (EMIF) 1920 ADCIN-B7

GPIO-58 / MCLKR-A / XD21 (EMIF) 1718 ADCIN-B6

Note:
EEPROM must be programmed
prior to first use using MProg3.5 or later.

NOTE:
RS232 interface not isolated by default.
For F28335 ControlCardR2.2-
Remove R13 and R24 on ControlCard.
Close switch SW1.
Provide isolated 3.3V source at connector.

Jumper must be connected
for Serial communications.
It must be unconnected for initial
EEPROM Programming.

Credits:
This design is based in part on
TI's USB Docking Station
Document C2000 - DAF [R3]

All Open = Flash Boot
JP6 Closed = SCI-A Boot
JP7 Closed = SPI-A Boot
Other Modes see Datasheet

University of Arkansas (NCREPT)

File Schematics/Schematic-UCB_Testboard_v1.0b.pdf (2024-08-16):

IDC Connector | Voltage Divider (ADC Test) | LED Outputs (I/O Test)


University of Arkansas (NCREPT)

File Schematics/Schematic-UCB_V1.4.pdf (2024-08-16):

# DIMM Interface (DIMM-B)

# DIMM Interface (DIMM-C)


GPIO-05 / EPWM-3B / MFSR-A / ECAP-1
GPIO-07 / EPWM-4B / MCLKR-A / ECAP-2

GPIO-09 / EPWM-5B / SCITX-B / ECAP-3
GPIO-11 / EPWM-6B / SCIRX-B / ECAP-4

GPIO-13 / TZ-2 / CANRX-B / MDR-B
GPIO-14 / TZ-3 / SCITX-B / MCLKX-B
GPIO-25 / ECAP-2 / EQEPB-2 / MDR-B
GPIO-27 / ECAP-4 / EQEPS-2 / MFSX-B

GPIO-17 / SPISOMI-A / CANRX-B / TZ-6

GPIO-21 / EQEPB-1 / MDR-A / CANRX-B
GPIO-23 / EQEPI-1 / MFSX-A / SCIRX-B

NOTE:
RS232 interface not isolated by default.
For F28335 ControlCardR2.2:
Remove R13 and R24 on ControlCard.
Close switch SW1.
Provide isolated 3.3V source at connector.

All Open = Flash Boot
JP8 Closed = SCI-A Boot
JP9 Closed = SPI-A Boot
Other Modes see Datasheet
DIMM-B_GPIO-84

JP15 Closed = SCI-A Boot
JP16 Closed = SPI-A Boot
DIMM-C_GPIO-84

University of Arkansas (NCREPT)

Unified Controller Board (UCB)

# Mounting Holes

IDC Interface (IDC-A) | IDC Interface (IDC-B) | IDC Interface (IDC-C) | IDC Interface (IDC-D)


University of Arkansas (NCREPT)

Unified Controller Board (UCB)

Bank_0 (IDC-A/IO) | Bank_1 (DIMM-B/IDC-B) | Bank_2 (DIMM-C/IDC-C)


University of Arkansas (NCREPT)

Unified Controller Board (UCB)

USB Input and TVS | Ext JTAG Header

# FTDI Chip (JTAG [TI] and Serial Int)


User I/O (Switches and LEDs)

Remove Jumper to Isolate
3.3V Supply from JTAG Connector.
Not Needed for ControlCard.

Jumper must be connected
for Serial communications.
It must be unconnected for initial
EEPROM Programming.

Note:
EEPROM must be programmed
prior to first use using MProg3.5 or
later.

FTDI Chip (JTAG Interface [Lattice])

Place close to CPLD.

Iso-VCC Range: 2.5V to 5.5V

USB Input and TVS

Use Right-Angle Connector
To Prevent Interferance with IDC

XPORT Ethernet Interface (ModBus TCP)

Reset Switch for XPORT

University of Arkansas (NCREPT)

Unified Controller Board (UCB)

# 9-36Vdc to 5V/3.3V/1.8V Converter (Digital)

# DC Power Entry (9V-36V)


University of Arkansas (NCREPT)

Unified Controller Board (UCB)

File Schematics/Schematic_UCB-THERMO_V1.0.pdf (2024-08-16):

Power Filtering and References (5V0,3V3,2V5) | Measurement Input Connectors\AMP | Scaling: VOUT = (TMJ × 5 mV/°C) + VREF


FILTER FREQUENCY(CM) =1/(2*pi*R*Cc)
WHERE Cd = 10xCc

University of Arkansas (NCREPT)

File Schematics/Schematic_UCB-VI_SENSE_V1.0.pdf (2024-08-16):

# External Sensor Power Supply (15V/-15V)

# Voltage Shift and Scaling


Scaling:
Burden resistors selected to provide +/- 2.5V or +/- 5V for respective sensors.
LEM LF 2005-S/SP23 => +/- 400mA MAX => [400mA * 6.19 Ohm] = 2.476 V
LEM LV 25-P => +/- 25mA RMS => [25mA * sqrt(2) * 140 Ohm] = 4.95 V

Power Filtering and References (5V0,3V3,2V5)

Pins 1-2 for LEM Current Sensors [LF 2005-S/SP23] (2000A Current)
Pins 2-3 for LEM Voltage Sensors [LV 25-P/SP5 ](500Vrms/1500 Vrms)

University of Arkansas (NCREPT)

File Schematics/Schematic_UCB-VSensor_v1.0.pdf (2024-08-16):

# Notes:

This PCB is meant for the LEM LV-25P series of Hall-Effect Voltage Sensors.


LEM LV-25P [500 Vrms] or LV 25-P/SP5 [1500 Vrms]

Input Resistors [R1-R3] (50k Ohm):
Select to provide 10mA nominal rms current.
Use R1 for 500 Vrms, R1-R2 for 1000 Vrms, and R1-R3 for 1500 Vrms.
Use shorting wires to for unused resistors.

External (Output) Burden Resistors:
LEM LV 25-P => +/- 25mA RMS => [25mA * sqrt(2) * 140 Ohm] = 4.95 V

External UCB Connector (+15/Mea/-15V)

HV Terminal and LEM LV-25P Sensor

University of Arkansas (NCREPT)

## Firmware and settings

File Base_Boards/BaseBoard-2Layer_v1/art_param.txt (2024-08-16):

DEVICE-TYPE           GERBER_RS274X
OUTPUT-UNITS          INCHES
FILM-SIZE             3000000 2000000
FORMAT                5.5
ABORT-ON-ERROR        NO
SCALE                 1
SUPPRESS-LEAD-ZEROES  YES
SUPPRESS-TRAIL-ZEROES NO
SUPPRESS-EQUAL        YES
UNDEF-APT-CONT        NO

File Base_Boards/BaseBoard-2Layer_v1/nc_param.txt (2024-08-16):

INTEGER-PLACES         2
DECIMAL-PLACES         4
X-OFFSET               0.000000
Y-OFFSET               0.000000
FEEDRATE               1
COORDINATES            ABSOLUTE
OUTPUT-UNITS           ENGLISH
TOOL-ORDER             INCREASING
REPEAT-CODES           YES
SUPPRESS-LEAD-ZEROES   NO
SUPPRESS-TRAIL-ZEROES  NO
SUPPRESS-EQUAL         NO
TOOL-SELECT            YES
OPTIMIZE_DRILLING      NO
ENHANCED_EXCELLON      YES
HEADER                 none
LEADER                 12
CODE                   ASCII
SEPARATE               NO
SEPARATE-ROUTING       NO
DRILLING               LAYER-PAIR
BACKDRILL              NO
CAVITY                 NO

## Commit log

2024-08-16 Initial Commit
    Initial Commit
    [BOM-UCB-Thermo_v1.0a.xlsx, BOM-UCB_PE-Eval_v1.5a.xlsx, BOM-UCB_Small_v2.1c -27Jun2017.xlsx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]
2025-08-12 Adding older UCB materials to archive folder
2025-08-12 Moving all UCBv1.4 materials to archive
2025-08-12 Moving all UCB 1.4 materials into archive folder
2025-08-12 Moving all UCB v1.4 files to archive folder
    [BOM-UCB-Thermo_v1.0a.xlsx, BOM-UCB_PE-Eval_v1.5a.xlsx, BOM-UCB_Small_v2.1c -27Jun2017.xlsx]
2025-08-12 Adding UCB 2.0 Design Materials
    [PCBWay- UCB_2-0_BOM (8).xlsx]
2025-08-12 Adding Schematic files
2025-08-12 Adding documentations for DSPs and FPGA. Also adding MProg for programming the FTDI chip for Lattice FPGA programming via USB port. Adding XPORT moduke settings and Typhoon HIL break board.
2025-08-12 Adding Supplemental materials
2025-08-12 Adding photos of PCB
